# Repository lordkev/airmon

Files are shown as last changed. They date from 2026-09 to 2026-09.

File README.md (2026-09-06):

# AirMon

A USB-powered home air-quality monitor built around the **Keyestudio 2.8-inch ESP32-WROOM-32E touchscreen board**, with a small sensor carrier, printable enclosure, offline web dashboard, HTTP API, and optional Home Assistant integration.

**Prototype r0.1 — digital design, not yet physically validated.** The exact display-board mating connector and PMSA003I socket fit must be confirmed before ordering the PCB. Firmware compilation and CAD checks do not establish hardware operation. See the [validation ledger](docs/VALIDATION.md) for completed checks and remaining release gates.

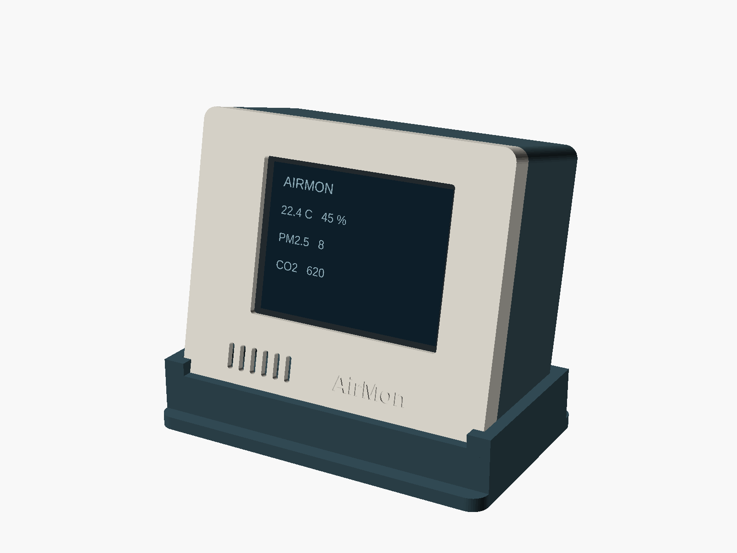
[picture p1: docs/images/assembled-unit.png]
Completed unit in its full enclosure and desktop stand


*CAD rendering of the full enclosure. LCD values are illustrative; this is not a photograph or firmware screenshot. Body: 100 × 82 × 44 mm, excluding the stand; shallow body: 100 × 82 × 30 mm.*

| Measurement | Sensor | Configuration |
|---|---|---|
| Temperature / relative humidity | SHT40 | Included on the carrier |
| PM1 / PM2.5 / PM10 | PMSA003I, Adafruit 4505 | Optional removable module |
| Actual CO₂ | SCD40, Adafruit 5187 | Optional STEMMA QT module |
| VOC / NOx indices | SGP41, Adafruit 6455 | Optional STEMMA QT module |

All sensors costing more than about $10 are optional. Add the PM module to meet the original temperature/humidity/PM2.5 minimum; the lowest-cost build measures temperature and humidity only. Gas indices do not identify individual chemicals, and AirMon does not replace a smoke or carbon-monoxide alarm.

## The circuit board

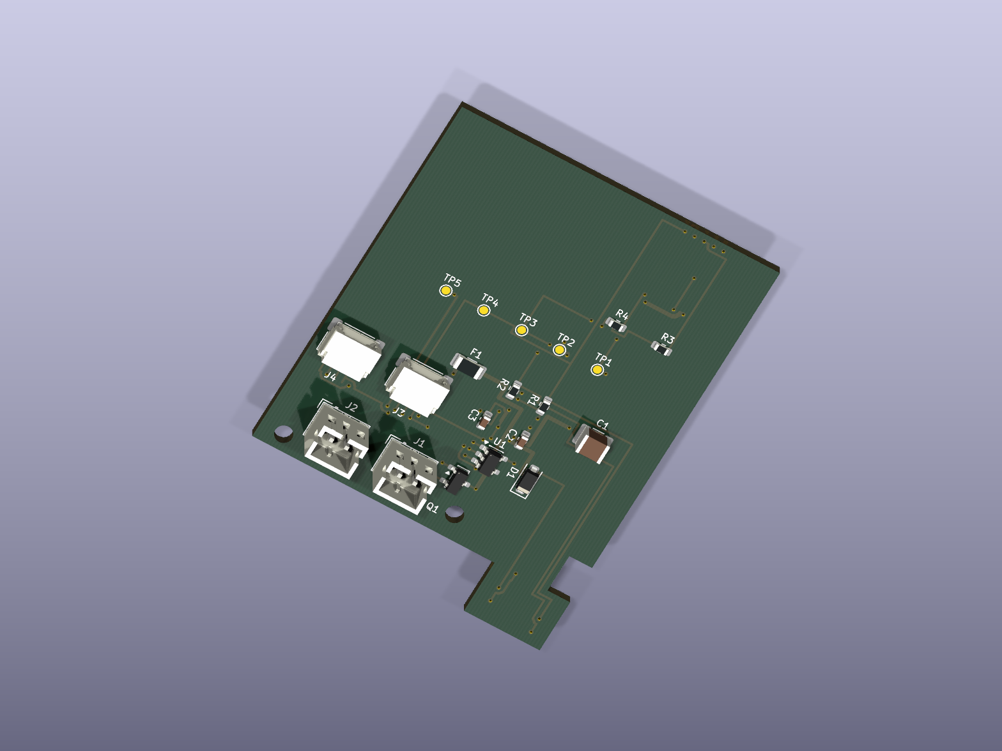
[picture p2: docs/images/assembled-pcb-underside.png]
Assembled sensor PCB, underside


*Native KiCad rendering of the routed 42 × 55 mm carrier, showing the regulator, protection, connectors, and test points. The SHT40 is on the opposite face of the extended tongue.*

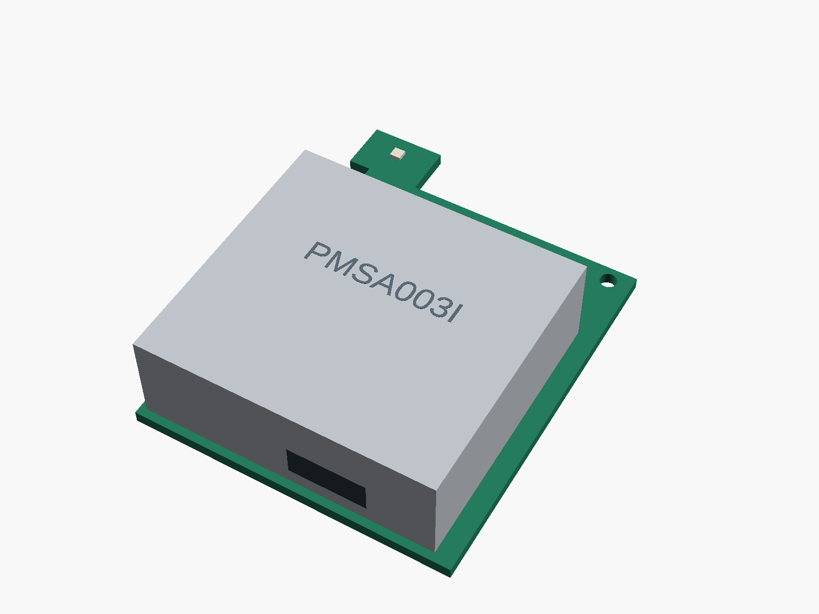
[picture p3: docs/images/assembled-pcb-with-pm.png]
Sensor carrier with optional PM module installed


*Mechanical rendering with the optional PMSA003I installed. Vendor modules and this view's carrier use simplified clearance envelopes; use the KiCad source and STEP for component-level details.*

## Build and use

1. Read [hardware and ordering](docs/HARDWARE.md), including the two connector checks.
2. Use the [BOM workbook](hardware/BOM.xlsx), [assembly CSV](hardware/assembly-bom.csv), and [purchasing CSV](hardware/purchasing-bom.csv).
3. Follow [printing and assembly](docs/ASSEMBLY.md), with the exploded CAD view.
4. [Build or flash the firmware](docs/FIRMWARE.md), then [configure and use AirMon](docs/USE.md).
5. Integrate through the [HTTP API](docs/API.md) or [MQTT/Home Assistant](docs/HOME_ASSISTANT.md).

## Deliverables

| Deliverable | Files |
|---|---|
| Editable electronics | [KiCad PCB](hardware/airmon.kicad_pcb), [schematic](hardware/airmon.kicad_sch), local libraries in `hardware/` |
| Manufacturing | [Gerber/drill ZIP](hardware/exports/airmon-gerbers.zip), [schematic PDF](hardware/exports/schematic.pdf), [assembly drawings and placement](hardware/exports/) |
| Mechanical | [PCB STEP](hardware/exports/airmon.step), [OpenSCAD source](enclosure/airmon.scad), [seven STL exports](enclosure/stl/) |
| Firmware | [ESP-IDF source](firmware/), [prototype binaries](release/firmware/) |
| Checks | [Validation ledger](docs/VALIDATION.md), [ERC](hardware/exports/erc.txt), [DRC](hardware/exports/drc.txt), [mesh checks](enclosure/mesh-validation.json), [CAD clearances](enclosure/clearance-validation.json) |
| Reproduction | [Development guide](docs/DEVELOPMENT.md), [requirements](PROMPT.md), [third-party notices](THIRD_PARTY.md) |

The project uses local Wi-Fi and HTTP. No cloud account or internet connection is required for normal readings; internet access is only used for optional clock synchronization and configured external services. History consists of 24 hours of one-minute means in RAM and resets at reboot.

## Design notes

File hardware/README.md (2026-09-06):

# AirMon carrier — prototype r0.1

Open `airmon.kicad_sch` and `airmon.kicad_pcb` in KiCad 10. Local symbols, footprints, and STEP models are included. The carrier is 42 × 55 mm overall, with a ventilated SHT40 tongue and optional PMSA003I mating socket.

Read [hardware and ordering](../docs/HARDWARE.md) before sending files to a manufacturer. **Exact display-board connector identification and the supplied PM socket fit remain unresolved physical checks.** ERC/DRC results apply to the digital design and do not remove these release gates.

- `exports/airmon-gerbers.zip`: copper, mask, silk, paste, outline, PTH and NPTH drill files.
- `exports/schematic.pdf`, `assembly-top.pdf`, `assembly-bottom.pdf`: electrical and assembly drawings.
- `exports/footprint-fit-1to1.pdf`: print at actual size to compare the supplied PM socket.
- `exports/placement-smt.csv`: SMT placement; J1/J2 require through-hole assembly separately.
- `BOM.xlsx`, `assembly-bom.csv`, `purchasing-bom.csv`: components and full purchasing data.
- `exports/airmon.step`: assembled carrier geometry.

J5 pad numbering follows Plantower, not the generic numbering in the Adafruit reference design. It must be checked against the supplied mating socket. Physical module models in enclosure illustrations are simplified envelopes.

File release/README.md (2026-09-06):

# AirMon prototype r0.1 deliverables

`firmware/` contains the four USB flash images, application-only OTA image, manifest, checksums, flash argument file, and dependency licenses. Flash instructions are in [docs/FIRMWARE.md](../docs/FIRMWARE.md).

Manufacturing files remain in [hardware/exports](../hardware/exports/), BOMs in [hardware](../hardware/), and print files in [enclosure/stl](../enclosure/stl/). This avoids maintaining duplicate copies with different revisions. The repository archive includes all of them.

**Prototype hold:** board-side connector identification, supplied PM socket fit, and physical electrical/mechanical/firmware tests are still pending. See [VALIDATION.md](../docs/VALIDATION.md). The renders illustrate the CAD design; they are not photographs of a tested product.

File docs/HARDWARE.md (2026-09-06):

# Hardware and ordering

## Release status

The PCB passes ERC/DRC. This is a **prototype engineering package**. Two purchased-part checks remain before fabrication: the display's exact 1.25 mm connector series and the PMSA003I supplied socket land pattern/mating height. Neither can safely be inferred from pitch alone. The BOM explicitly marks the unresolved board housing.

Match the delivered [Keyestudio board](https://www.keyestudio.com/products/28-inch-esp32-32e-display-screen-lcd-tft-module-with-touch-wroom-for-arduino) to [LCDWIKI E32R28T documentation](https://www.lcdwiki.com/2.8inch_ESP32-32E_Display). This project targets classic ESP32, 4 MB flash, ILI9341V LCD, and XPT2046 touch. Similarly sized boards may have different pinouts.

## Carrier and pins

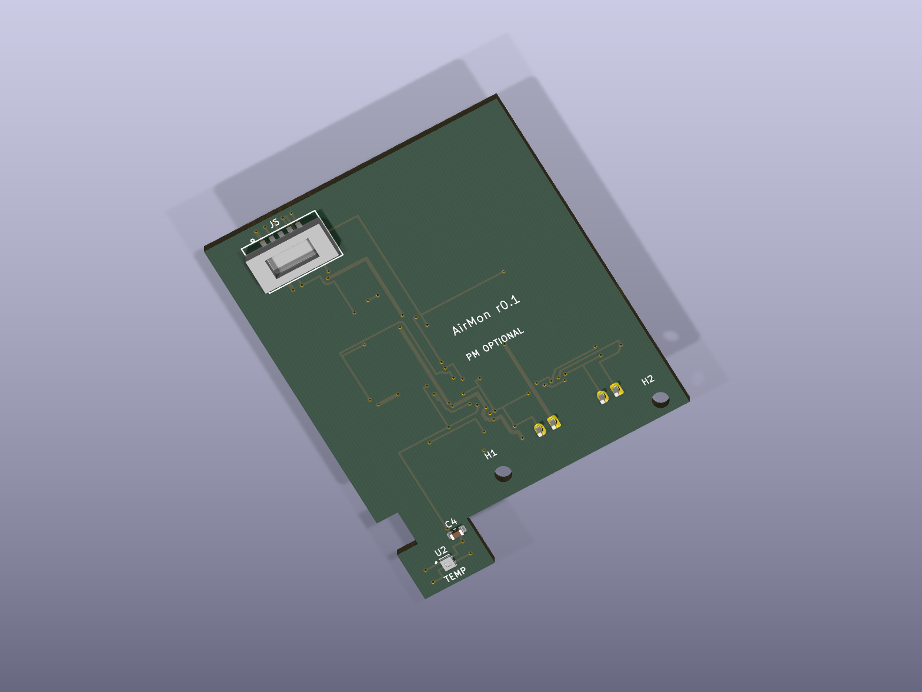
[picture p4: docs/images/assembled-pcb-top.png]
Native KiCad top view of the assembled carrier


*The optional PM socket is at the top of the board; SHT40 sits on the lower tongue. Simplified socket/sensor STEP envelopes still require a mating-height check.*

The carrier has a 42 × 48 mm main area plus a 10 × 7 mm SHT40 extension, 42 × 55 mm overall. It uses two copper layers and 1.6 mm FR-4. PMSA003I sits on top; power components and cable connectors sit underneath. Two M2 holes and printed edge guides support it.

| Function | ESP32 GPIO |
|---|---|
| LCD MOSI / MISO / SCLK | 13 / 12 / 14 |
| LCD CS / DC / backlight | 15 / 2 / 21 |
| Touch MOSI / MISO / SCLK | 32 / 39 / 25 |
| Touch CS / IRQ | 33 / 36 |
| Sensor SDA / SCL | 19 / 18 |
| Sensor 5 V enable | 22, LOW; shares red LED |
| Unused audio disable | 4, HIGH |
| SD deselect | 5, HIGH; card slot must stay empty |

LCD reset follows ESP32 EN. GPIO19/18 share the disabled microSD interface. The switched UART supply comes through the display-board Q5 circuit. GPIO22 HIGH does not guarantee full power disconnection because its gate drive is 3.3 V and its source is USB 5 V. Disconnect USB for service. Battery operation is unsupported. [Manufacturer schematic](https://www.lcdwiki.com/res/E32R28T/2.8inch_ESP32-32_Display_Schematic.pdf).

## Harnesses

These are schematic pin numbers, **not left-to-right visual instructions**. Identify pin 1 and verify continuity on the actual board. Do not rely on wire colors or assume the same view at opposite connector ends.

| Harness | Display end | Carrier end | Suggested color |
|---|---|---|---|
| POWER | UART P2 pin 1, switched USB 5 V | J1 pin 1 | Red |
| POWER | UART P2 pin 2, GND | J1 pin 2 | Black |
| I2C | SPI P3 pin 2, GPIO19 | J2 pin 1, SDA | Blue |
| I2C | SPI P3 pin 3, GPIO18 | J2 pin 2, SCL | Yellow |

Leave UART TXD/RXD pins 3/4, SPI GPIO23/GPIO27 pins 1/4, and connector shield/mounting positions out of the signal harness. Common ground comes through POWER. Target 100 mm wires, 26 AWG stranded. Carrier mating parts: JST **PHR-2** housings and **SPH-002T-P0.5S** contacts, mating to **B2B-PH-K-S(LF)(SN)**. Board ends must use confirmed matching pigtails or a positively identified housing/contact set; their exact MPN is still pending.

J1 and J2 are electrically different but mechanically interchangeable: label both harnesses and never swap them. J3/J4 use JST SH STEMMA QT pinout: 1 GND, 2 sensor 3.3 V, 3 SDA, 4 SCL. Do not apply 5 V to QT.

## Optional modules

| Module | Address | Procurement |
|---|---|---|
| SHT40 | `0x44` | Required SMT sensor on carrier |
| PMSA003I | `0x12` | [Adafruit 4505](https://www.adafruit.com/product/4505), bare I²C module with mating socket |
| SCD40 | `0x62` | [Adafruit 5187](https://www.adafruit.com/product/5187), plus QT cable |
| SGP41 | `0x59` | [Adafruit 6455](https://www.adafruit.com/product/6455), plus QT cable |

The PM part is not PMSA003 UART, PMS5003, or the larger Adafruit breakout. Socket numbering follows the [Plantower manual](https://cdn-shop.adafruit.com/product-files/4632/4505_PMSA003I_series_data_manual_English_V2.6.pdf): 1/2 VCC, 3/4 GND, 5 RESET, 6 NC, 7 SCL, 8 NC, 9 SDA, 10 SET. R3/R4 hold RESET/SET high at 3.3 V. Generic Eagle connector numbering in the Adafruit reference differs; check the mating view before translating numbers.

For later plug-in PM upgrades, have the supplied J5 socket consigned and fitted during PCBA assembly. If omitted, adding PM requires one-time socket soldering. No independently verified socket order code is claimed. Check it against the [1:1 footprint print](../hardware/exports/footprint-fit-1to1.pdf) and measure the assumed 2 mm mating height before fabrication.

## Power and I²C budget

Use a regulated 5 V, 2 A USB-A supply and short USB-A-to-C data cable. The following is a **design allowance, not a measurement**: display/ESP32 600 mA peak, PM 100 mA active plus 100 mA startup margin, and the 3.3 V sensor rail 250 mA including CO₂ pulses, gas heater, pull-ups, breakout LEDs, and margin. Total allowance: 1.05 A at 5 V. Validate the display-board USB connector/Q5 path and actual cable drop under load.

SCD40 specifies 205 mA peak and 15 mA average at 3.3 V. SGP41 specifies 3.0 mA typical measurement average and 4.6 mA maximum conditioning average at 3.3 V. Breakout overhead and pulse loads require bench testing. [SCD40 specifications](https://sensirion.com/products/catalog/SCD40), [SGP41 datasheet, table 2](https://sensirion.com/media/documents/5FE8673C/61E96F50/Sensirion_Gas_Sensors_Datasheet_SGP41.pdf).

AP2112K U1 is rated 600 mA and has ceramic input/output decoupling. At the 250 mA allowance, `(5 − 3.3) × 0.25 = 0.425 W` is an instantaneous dissipation estimate. The datasheet's 184 °C/W junction-to-ambient figure would imply a 78 °C rise if that load were continuous; that is not an acceptable assumed continuous operating point in warm ambient conditions. Expected average sensor current is much lower, but verify regulator temperature and rail droop fully populated. [AP2112 datasheet](https://www.diodes.com/assets/Datasheets/AP2112.pdf).

F1 is a 1 A hold resettable fuse in the carrier branch; Q1 protects against reverse input polarity. D1 is a transient suppressor, **not regulated overvoltage protection**: its clamp can exceed the LDO absolute input rating. Use regulated USB 5 V only. C1 provides local bulk capacitance; measure PM startup droop instead of assuming it is eliminated.

The carrier has 4.7 kΩ pull-ups per I²C line. Each referenced gas breakout has **two 10 kΩ branches per line**, on opposite sides of its MOSFET level shifter. When LOW, both branches contribute current; treating their supplies as 3.3 V gives a conservative 5 kΩ equivalent per installed breakout. Actual sensor-side voltage is affected by its onboard regulator. Check the delivered revisions and PM idle resistance.

| PM | CO₂ | VOC/NOx | Conservative LOW equivalent | LOW current, 3.3 V |
|---|---|---|---|---|
| Off | Off | Off | 4.70 kΩ | 0.70 mA |
| On | Off | Off | 4.70 kΩ | 0.70 mA |
| Off | On | Off | 2.42 kΩ | 1.36 mA |
| On | On | Off | 2.42 kΩ | 1.36 mA |
| Off | Off | On | 2.42 kΩ | 1.36 mA |
| On | Off | On | 2.42 kΩ | 1.36 mA |
| Off | On | On | 1.63 kΩ | 2.02 mA |
| On | On | On | 1.63 kΩ | 2.02 mA |

The table assumes PM adds no pull-ups; include any internal pull-up found by measurement. These LOW-current equivalents are not a complete level-shifter rise-time model. At 100 kHz, a 4.7 kΩ pull-up and assumed 200 pF bus give `tr ≈ 0.8473 × R × C = 0.80 µs`. Measure rise time and LOW voltage at the farthest module for all eight configurations. Capacitance and actual module pull-up currents have not been measured. All four sensor addresses are distinct.

## PCBway order package

After resolving the connector checks, upload [airmon-gerbers.zip](../hardware/exports/airmon-gerbers.zip) for two-layer, 1.6 mm FR-4, 1 oz copper. Specify solder mask both sides and a lead-free finish; no controlled impedance is required. Use the manufacturer's standard finish or ENIG for fine-pitch assembly. This layout uses approximately 0.25 mm minimum tracks and 0.20 mm clearance, with 0.30 mm via drills and 0.60 mm pads. Preserve the outline and SHT40 tongue exactly.

For assembly, supply [assembly-bom.csv](../hardware/assembly-bom.csv), [placement-smt.csv](../hardware/exports/placement-smt.csv), [fabrication drawing](../hardware/exports/fabrication-drawing.pdf), [top](../hardware/exports/assembly-top.pdf) and [bottom](../hardware/exports/assembly-bottom.pdf) drawings, and [schematic](../hardware/exports/schematic.pdf). Placement uses KiCad drill origin and millimetres; bottom coordinates are not X-negated. Confirm bottom orientation and polarized pin 1 in the assembler's preview. J1/J2 need a separate through-hole step; J5 is optional and may need consignment. Test points and holes are not purchased parts.

Do not wash or conformally coat over SHT40. Agree on a sensor-compatible assembly process. [BOM.xlsx](../hardware/BOM.xlsx) distinguishes listed prices, estimates, and unknown quotes, dated 2026-09-06. PCBA setup, stencil, shipping, taxes, and uncertain harness pricing are not included in a purported total.

## First power checks

With USB disconnected, verify no 5 V-to-GND short and check each harness conductor against the table. Flash the display with the carrier disconnected so GPIO22 is configured. Confirm UART P2 pin 1 is near 5 V relative to pin 2. Remove USB, connect the carrier without optional modules, then power while monitoring current.

Measure TP1 GND, TP2 SENSOR5V, TP3 SENSOR3V3, TP4 SDA, and TP5 SCL. Target TP3 at 3.3 V ±5%. PM needs 4.5–5.5 V at its input, including startup dips; use an oscilloscope. Unplug before adding each module. Record total current, rail minima, regulator temperature, I²C rise time, and behavior at minimum/maximum brightness for all eight module combinations. Finish with the [fully populated 24-hour run](VALIDATION.md#physical-acceptance-procedure).

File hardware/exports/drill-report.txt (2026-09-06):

Drill report for airmon.kicad_pcb
Created on 2026-09-06T13:42:37

Copper Layer Stackup:
    =============================================================
    L1 :  F.Cu                      front
    L2 :  B.Cu                      back

Drill file 'airmon-PTH.drl' contains
    plated through holes:
    =============================================================
    T1  0.300mm  0.0118"  (60 holes))
    T2  0.750mm  0.0295"  (4 holes))

    Total plated holes count 64

Drill file 'airmon-NPTH.drl' contains
    unplated through holes:
    =============================================================
    T1  2.200mm  0.0866"  (2 holes))

    Total unplated holes count 2

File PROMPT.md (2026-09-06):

# Keyestudio touchscreen air-quality monitor

## Summary

Build a USB-powered desktop monitor around the [Keyestudio 2.8-inch ESP32-32E touchscreen board](https://www.keyestudio.com/products/28-inch-esp32-32e-display-screen-lcd-tft-module-with-touch-wroom-for-arduino), with a compact custom sensor PCB, printable PLA enclosure, local web dashboard, HTTP API, and Home Assistant integration.

Use a landscape touchscreen layout. Temperature and humidity are included; PM, CO₂, and VOC/NOx modules can be purchased and plugged in independently. All configurations use the same firmware.

## Hardware and manufacturing

### Sensor configuration

| Measurement | Hardware | Installation |
|---|---|---|
| Temperature/humidity | Sensirion SHT40 | Assembled on sensor PCB |
| PM1, PM2.5, PM10 | Plantower PMSA003I bare module | Removable matching socket |
| Actual CO₂ | Adafruit SCD40 breakout, product 5187 | Internal STEMMA QT cable |
| VOC/NOx indices | Adafruit SGP41 breakout, product 6455 | Internal STEMMA QT cable |

Every sensor costing more than approximately $10 remains optional and independently installable after assembly.

### Sensor PCB and connections

- Design a two-layer KiCad PCB using standard 1.6 mm FR-4 and 1 oz copper. Minimize its outline around the PM socket, sensor placement, and connectors; it need not span the display board.
- Mount it behind the display using enclosure standoffs and short cable harnesses. Provide factory SMT assembly files; users install cables and optional modules.
- Connect I²C through the Keyestudio expansion connector: **GPIO19 SDA, GPIO18 SCL**, with 3.3 V logic. Keep microSD disabled and its slot empty because these pins share the SD interface. [Board pin allocation](https://www.lcdwiki.com/2.8inch_ESP32-32E_Display)
- Obtain USB-derived 5 V and ground from the UART connector using a power-only harness; leave UART signal pins disconnected. Reserve **GPIO22 low** to enable this supply, accounting for its shared red-LED function. Verify connector numbering and the delivered board revision against the [schematic](https://www.lcdwiki.com/res/E32R28T/2.8inch_ESP32-32_Display_Schematic.pdf).
- Feed the PM sensor from 5 V and provide a dedicated regulated 3.3 V sensor rail. Include decoupling, appropriate protection, test points, and a calculated startup/peak-current budget.
- Use keyed STEMMA QT connections for gas modules and expansion. Check combined I²C pull-ups and voltage levels with every supported module combination.
- Place the SHT40 at a ventilated lower edge on a thermally isolated PCB section, away from the display, processor, regulator, gas-sensor heaters, and PM exhaust.
- Keep the ESP32 antenna region clear of sensor modules, copper, and cables. Verify connector mating heights and cable bend space in assembled CAD.

### Manufacturing deliverables

Deliver editable KiCad sources and local libraries, schematic PDF, PCB STEP model, Gerber/drill ZIP, fabrication drawing, placement CSV, assembly drawings, and assembly BOM suitable for PCBway.

Provide a separate complete purchasing BOM covering the display board, components, optional modules, exact mating connectors and harnesses, fasteners, printed parts, and a 5 V USB supply. Include manufacturer part numbers, quantities, sourcing links, dated prices, and required/optional classifications.

## Enclosure

- Create a parametric OpenSCAD enclosure and export printable STLs alongside editable source.
- Use a landscape front bezel with a stable, slightly reclined desktop base, rear shell, and removable internal sensor mounts.
- Design around the display board’s approximately **86 × 50 mm** outline. Final enclosure depth follows the assembled sensor and cable clearances. [Mechanical documentation](https://www.lcdwiki.com/2.8inch_ESP32-32E_Display)
- Provide shallow and full-sensor rear-shell variants sharing the front bezel. The full version accommodates PM, CO₂, and VOC/NOx simultaneously.
- Target PLA, a 0.4 mm nozzle, 0.2 mm layers, support-free printing, and screws with captive nuts.
- Preserve touchscreen edge clearance so the bezel cannot press on the resistive panel. Include USB access, BOOT/RESET access, strain relief, and secure mounting through the board’s mounting holes.
- Separate PM intake and exhaust openings to limit recirculation. Give the temperature and gas sensors direct room-air exposure while limiting heat transfer from electronics.
- Supply print orientations, assembly illustrations, and a small fit-test print for fasteners and mating clearances.

## Firmware and interfaces

### Device firmware and touchscreen

- Use ESP-IDF targeting the classic **ESP32**, with pinned dependencies, ILI9341 display support, XPT2046 resistive-touch support, and LVGL using partial display buffers.
- Use separate SPI controllers for display and touch, following the board’s wiring. Reserve the repurposed expansion pins exclusively for sensor I²C.
- Show temperature, humidity, PM2.5, CO₂, and gas indices on the landscape overview. Tapping a metric opens its trend and sensor status; provide large touch targets and a settings page.
- Include first-use touch calibration, saved calibration, and a recalibration option. BOOT remains a fallback control: short press changes pages; a five-second press during normal operation opens Wi-Fi setup.
- Default backlight brightness to 30%, with adjustable brightness and a configurable dimming timer.
- Implement independent sensor drivers with CRC/checksum validation, startup timing, retries, and explicit absent, warming-up, valid, stale, and failed states.
- Use SHT40 readings for ambient measurements and SGP41 compensation. Apply Sensirion’s Gas Index Algorithm; expose VOC/NOx as indices, never estimated CO₂ or identified chemical concentrations.
- Provide documented CO₂ calibration controls and temperature correction. Disable automatic CO₂ baseline calibration by default until the user enables it under suitable placement conditions.

### Networking, web dashboard, and API

- On first boot, create a password-protected setup AP with credentials displayed onscreen, captive-portal support, and a direct setup address. Keep phone/browser provisioning as the primary Wi-Fi setup flow.
- Commit new Wi-Fi credentials after a successful connection. Preserve existing credentials through failed changes and network outages; allow physical re-entry to setup.
- Serve a responsive local dashboard with live measurements, sensor health, settings, and 24-hour charts. Store one-minute aggregates in RAM and indicate that history resets on reboot.
- Embed all web assets in firmware; require no cloud account, CDN, or internet connection for normal operation.
- Expose `GET /api/v1/readings`, `/status`, `/history`, and `/config`; `PUT /api/v1/config`; and `POST /api/v1/firmware`.
- Include measurement units, timestamps or uptime, reading age, and validity. Represent unavailable values as `null`.
- Protect configuration changes and firmware uploads with a per-device administrator credential. Keep measurement reads available on the local network and document HTTP’s security assumptions.
- Add optional MQTT configuration, Home Assistant discovery, stable device/entity identifiers, availability reporting, and automatic reconnection.
- Support browser firmware uploads with two OTA application slots and rollback. Keep compressed assets inside each application image and enforce flash/RAM budgets for the 4 MB board. Retain USB flashing and recovery.

## Validation and delivery

- **Electrical:** Pass ERC/DRC; review footprints, harness pinouts, shared GPIO functions, power startup, rail voltage under load, and every optional-sensor combination.
- **Mechanical:** Check assembled-model collisions, antenna clearance, airflow, touchscreen clearance, fasteners, printable meshes, and sliced orientations.
- **Software:** Test sensor parsing, corrupted data, missing sensors, history rollover, touch calibration, provisioning, configuration persistence, Wi-Fi/MQTT recovery, Home Assistant discovery, and interrupted OTA.
- **Physical prototype:** Verify enclosure fit, touch operation while assembled, viewing angle, fully populated power consumption, a 24-hour operating run, and temperature bias against a separate reference.
- **Documentation:** Include ordering, printing, assembly, tool installation, compilation, prebuilt firmware flashing, USB recovery, configuration, calibration, API examples, dashboard use, Home Assistant setup, and troubleshooting.
- **Release package:** Deliver editable sources, manufacturing files, complete BOMs, STLs, firmware binaries, documentation, and validation results. Clearly distinguish completed checks from physical tests still pending.

Defaults remain indoor desktop use, USB power, PLA, plug-in upgrades, and no firm overall budget cap. Battery operation, audio, persistent microSD logging, and additional gas species are outside the first version. Confirm the purchased Keyestudio revision matches the documented E32R28T hardware before fabrication; label the initial release as a prototype until physical validation is complete.

## Additional documentation requirement

Include renders of the assembled circuit board and the completed unit in its 3D-printed enclosure. Also provide an exploded assembly view showing the display board, sensor carrier, optional sensor modules, and enclosure parts.

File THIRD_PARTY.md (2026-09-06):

# Third-party materials

This private project's original source has not been assigned a public redistribution license. Third-party components retain their own licenses and notices.

- **KiCad community libraries:** selected standard footprints and STEP models are copied into `hardware/AirMon.pretty` and `hardware/models`. Local model paths were changed; the custom PMSA003I supplied-socket footprint/model and simple SHT40 envelope are project-generated. KiCad libraries use CC BY-SA 4.0 with the electronic-design exception. The upstream [license document](hardware/licenses/KiCad-LICENSE.md) and [KiCad policy](https://www.kicad.org/libraries/license/) explain the distinction between design use and library redistribution. Original STEP headers/footprint descriptions are retained.
- **Adafruit Industries:** PMSA003I, SCD4x, and SGP41 public reference PCB designs were consulted for mechanical and connector dimensions. Upstream URLs and exact commits appear in [the manifest](hardware/references/manifest.json). Those reference repositories use [CC BY-SA 3.0](hardware/licenses/Adafruit-CC-BY-SA-3.0.txt). The AirMon schematic/layout is newly generated; vendor display and gas-module illustrations are simplified envelopes, not redistributed vendor board CAD.
- **Sensirion:** the unmodified floating-point Gas Index Algorithm is vendored in `firmware/components/gas_index`, with [BSD-3-Clause license](firmware/components/gas_index/LICENSE) and [upstream commit](firmware/components/gas_index/UPSTREAM.md).
- **Espressif ESP-IDF v5.5.1:** Apache-2.0 SDK plus third-party components, including Wi-Fi/PHY libraries, mbedTLS, and cJSON. SDK and managed-component sources are fetched by the documented build workflow rather than committed here.
- **LVGL 9.2.2:** MIT. **ILI9341 2.0.1** and **mDNS 1.8.2:** see their bundled upstream license files. Dependency versions and hashes are pinned in `firmware/dependencies.lock`.

Copies of the relevant binary dependency licenses are included in [release/firmware/licenses](release/firmware/licenses/). Refer to the pinned SDK source for its complete component notices. Manufacturer datasheets are linked and hashed where downloaded; the original documents are not redistributed in the release package.

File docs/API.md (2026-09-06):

# HTTP API v1

Base URL: `http://DEVICE_IP/api/v1`. The same API is available at `http://192.168.4.1/api/v1` while connected to the setup AP. Requests and responses use UTF-8 JSON except the firmware binary upload and the noted text responses. The device does not grant cross-origin browser access.

## Authentication and errors

GET endpoints are readable without authentication. All mutations require `Authorization: Bearer TOKEN`, where TOKEN is the 32-character administrator credential displayed on the LCD. HTTP is not encrypted; use a trusted LAN. Missing/incorrect tokens return `401` and `{"error":"Administrator token required"}`.

Other error statuses include `400` invalid input/upload, `409` busy or unavailable calibration, `413` JSON outside the 1–2,048 byte limit, and `503` insufficient history-response memory. Error bodies normally contain an `error` string. Unknown `/api/` GET routes return `404`.

## Endpoints

| Method | Path after `/api/v1` | Result |
|---|---|---|
| GET | `/readings` | Current measurements, units, validity and age |
| GET | `/status` | Firmware/network/heap/config/sensor status |
| GET | `/history?limit=180&before=...` | Paginated minute aggregates |
| GET | `/config` | Redacted configuration |
| PUT | `/config` | Partial settings update; `202` means pending |
| POST | `/calibration/co2` | Forced CO₂ calibration request; `202` |
| POST | `/calibration/touch` | Begin LCD touch calibration; `200` text |
| POST | `/firmware` | Raw application binary; `200` text then reboot |

## Readings

```sh
curl http://DEVICE_IP/api/v1/readings
```

The response contains `uptime_ms`, `timestamp` (Unix seconds or `null`), and `metrics`. Each metric is an object with `value`, `unit`, `status`, and `age_ms`. Illustrative metric entry:

```json
{"value":22.4,"unit":"°C","status":"valid","age_ms":540}
```

| Key | Unit | Source |
|---|---|---|
| `temperature` | `°C` | SHT40 plus configured correction |
| `humidity` | `%` | SHT40 |
| `pm1`, `pm2_5`, `pm10` | `µg/m³` | PMSA003I atmospheric/environmental fields |
| `co2` | `ppm` | SCD40 actual CO₂ |
| `voc_index`, `nox_index` | `index` | Sensirion Gas Index Algorithm |

All eight keys are present. Unavailable values are `null`, never zero as a missing-data sentinel. Status is `absent`, `warming_up`, `valid`, `stale`, or `failed`. A reading expires after 5 seconds, or 15 seconds for CO₂. `age_ms` is elapsed time since the last received sample; it is `null` if no sample exists. A warming sample may have an age but still has a null value. These gas indices are not estimated CO₂, ppm of a particular VOC, or an AQI.

## Status

`GET /status` returns `version`, `device_id` (12 hexadecimal MAC-derived characters), `board`, `uptime_ms`, `free_heap`, `minimum_free_heap`, `wifi_connected`, `ip`, `ap_active`, `mqtt_connected`, `config_pending`, `config_result`, `touch_calibrated`, `ota_busy`, `history_points`, and `sensor_errors`.

Heap values are bytes. `sensor_errors` is a four-element counter array in SHT40, PMSA003I, SCD40, SGP41 order. Counters and history reset on reboot. Poll `config_pending` and `config_result` after an asynchronous configuration or CO₂ calibration request. No passwords or administrator token are included.

## History

```sh
curl 'http://DEVICE_IP/api/v1/history?limit=180'
```

The response shape is:

```json
{
  "resolution_seconds":60,
  "persistent":false,
  "points":[
    {"uptime_s":120,"timestamp":null,"temperature":22.4,"humidity":45.1,"pm1":null,"pm2_5":null,"pm10":null,"co2":null,"voc_index":null,"nox_index":null}
  ],
  "next_before":120
}
```

`limit` is 1–180, default 180. Both numeric query fields accept decimal digits only; signs, suffixes, fractions, uint32 overflow, and oversized/truncated query strings return `400`. `before` is an exclusive unsigned uptime-second boundary, not an epoch time. The latest eligible points are selected and returned oldest-to-newest. To fetch older pages, pass `next_before` as `before` and prepend their points. Stop on an empty/short page or `next_before:null`. Eight full pages cover 1,440 points. A full final page can legitimately require one extra empty request to establish the end.

Values are minute means of fresh valid samples. The incomplete current minute is omitted. Missing minutes/metrics remain null. UTC may be absent until SNTP succeeds; use uptime for stable ordering. Discard prior pagination state after a device reboot.

## Configuration

`GET /config` returns the fields below except passwords, plus `wifi_password_set` and `mqtt_password_set`. The PUT operation is a partial update despite its method name: omitted fields retain their values. Unknown fields and incorrect types are rejected.

| Field | Type / limits | Default |
|---|---|---|
| `name` | Nonempty string, at most 32 UTF-8 bytes | `AirMon xxxxxx` |
| `ssid` | Nonempty string, at most 32 UTF-8 bytes | Empty until provisioned |
| `password` | Empty for open Wi-Fi, otherwise 8–63 bytes | Empty |
| `brightness` | Integer, 5–100 percent | 30 |
| `dim_seconds` | Integer, 0–3,600; zero disables dimming | 120 |
| `temperature_offset` | Number, −10 to +10 °C | 0 |
| `altitude_m` | Integer, 0–3,000 m | 0 |
| `co2_asc` | Boolean | false |
| `mqtt_enabled` | Boolean | false |
| `mqtt_uri` | String, at most 192 bytes; `mqtt://` or `mqtts://` when enabled | Empty |
| `mqtt_user` | String, at most 64 bytes | Empty |
| `mqtt_password` | String, at most 128 bytes | Empty |

Control characters are rejected in strings. Use the separate MQTT credential fields; credentials embedded in broker URIs are rejected because the URI is returned by GET config. Password omission preserves a stored password, while `"password":""` explicitly clears it. Do not PUT the GET response wholesale: the two read-only password-set flags are not accepted input fields. A Wi-Fi SSID is required in the resulting configuration, including for a first settings update.

```sh
curl -X PUT http://DEVICE_IP/api/v1/config \
  -H 'Authorization: Bearer TOKEN' -H 'Content-Type: application/json' \
  --data '{"ssid":"My Wi-Fi","password":"replace-this-password","name":"Living room"}'
```

`202 {"status":"pending"}` means the change was queued. New Wi-Fi credentials are tested for up to 40 seconds before persistence. Failed changes retain/restore the previous settings. A concurrent configuration or firmware update returns `409`. Poll `/status`; connection changes may require reconnecting to the new device IP. The setup AP closes 60 seconds after a successful connected save.

## Calibration

```sh
curl -X POST http://DEVICE_IP/api/v1/calibration/co2 \
  -H 'Authorization: Bearer TOKEN' -H 'Content-Type: application/json' \
  --data '{"reference_ppm":420}'
```

Use your actual known reference, not the example blindly. `reference_ppm` must be an integer from 400–2,000. CO₂ must be fresh/valid and periodic measurement must have run for at least three minutes. Success returns `202 {"status":"calibration_pending"}`; completion/failure appears in `config_result`. This is not a substitute for stable reference air.

```sh
curl -X POST http://DEVICE_IP/api/v1/calibration/touch \
  -H 'Authorization: Bearer TOKEN'
```

Touch calibration takes place on the LCD. The response is plain text, `Touch calibration started on the display`.

## Firmware upload

```sh
curl -X POST http://DEVICE_IP/api/v1/firmware \
  -H 'Authorization: Bearer TOKEN' -H 'Content-Type: application/octet-stream' \
  --data-binary @release/firmware/airmon.bin
```

Send a normal Content-Length upload of the application `.bin`, not multipart/form-data or a chunked request. The maximum image size is the inactive slot size, 1,966,080 bytes. Success returns plain text `Firmware validated. Rebooting.` The device reboots shortly afterwards. Invalid/incompatible/incomplete uploads return `400` and keep the current image selected. See [firmware and recovery](FIRMWARE.md) for rollback behavior and pending hardware tests.

## Live acceptance checks

Once a prototype is flashed and reachable, run the read-only checker from the repository root:

```sh
python3 scripts/test_device_api.py http://DEVICE_IP
```

It checks real HTTP responses, metric/null/freshness semantics, history pagination, malformed query rejection, redacted configuration, dashboard delivery, and three concurrent readers. The JSON report defaults to `tmp/device-api-validation.json`. It sends no configuration, calibration, or firmware updates. An empty history can pass structural checks; it is not evidence of a 24-hour run. Hardware-dependent tests in the validation ledger remain separate.

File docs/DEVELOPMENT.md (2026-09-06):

# Reproducing the design

The checked-in native files are editable without regeneration. Scripts that generate the board or schematic overwrite their output; preserve manual edits before running them. The repository does not include downloaded SDKs, native applications, virtual environments, or build caches.

## Tools

| Area | Version used |
|---|---|
| Electronics | KiCad 10.0.6, including its `pcbnew` Python module |
| Enclosure | OpenSCAD 2026.09.05, manifold backend |
| Mechanical checks | Python 3.12; CadQuery 2.8.0, trimesh 5.1.0, manifold3d 3.5.2 |
| Firmware | ESP-IDF v5.5.1, esptool 4.12.0, locked managed components |
| Slicing check | Bambu Studio 02.08.02.61; isolated A1 0.4 mm / Generic PLA reference profile |
| Host software tests | Clang with AddressSanitizer/UndefinedBehaviorSanitizer; Node 24 and Playwright/Chrome |
| BOM authoring | Node with `@oai/artifact-tool`; CSVs and XLSX are already delivered |

Install KiCad from [kicad.org](https://www.kicad.org/download/) and OpenSCAD from [openscad.org](https://openscad.org/downloads.html). Set `KICAD_CLI`, `KICAD_SHARE`, and `OPENSCAD` if executables/libraries are outside normal locations. `KICAD_CONFIG_HOME` can point to a private configuration directory. Run PCB Python scripts with KiCad's bundled Python, which has `pcbnew` available; other scripts use ordinary Python.

## Electronics

For export from the existing native files:

```sh
python3 scripts/export_hardware.py
KICAD_PYTHON scripts/check_netlist.py
python3 scripts/fabrication_drawing.py
```

Replace `KICAD_PYTHON` with the executable path for KiCad's Python. `fabrication_drawing.py` needs `reportlab`. The exporter requires successful ERC/DRC, produces PDFs/netlist/Gerbers/drills/placement/STEP, and verifies that the manufacturing ZIP contains the copper layers as well as drills. The independent connectivity check compares every connected schematic pin with PCB pad nets.

Full regeneration, only when you intend to replace the editable layout:

```sh
KICAD_PYTHON scripts/build_hardware.py
python3 scripts/prepare_models.py
KICAD_PYTHON scripts/build_hardware.py
KICAD_PYTHON scripts/route_hardware.py
python3 scripts/build_schematic.py
python3 scripts/export_hardware.py
KICAD_PYTHON scripts/check_netlist.py
```

The first board pass prepares footprint copies; model preparation attaches local STEP paths; the second pass loads those models. Routing uses a two-layer grid search and explicit fine-pitch escape rules. Inspect regenerated geometry and drawings even after a clean DRC. `components.json` records the net/pad specification. Vendor sources and commits are in [the reference manifest](../hardware/references/manifest.json).

To render the actual populated PCB:

```sh
kicad-cli pcb render --side bottom --rotate '25,0,30' --zoom 0.65 \
  --quality high --background opaque --floor --width 1600 --height 1200 \
  -o docs/images/assembled-pcb-underside.png hardware/airmon.kicad_pcb
```

Use `--side top` and a different output name for the top view. Documentation enclosure/module renders come directly from OpenSCAD; no generated product photography is used.

## Mechanical export and checks

```sh
python3 -m venv .venv-cad
. .venv-cad/bin/activate
python -m pip install cadquery==2.8.0 trimesh==5.1.0 manifold3d==3.5.2 networkx
python scripts/export_enclosure.py
python scripts/validate_meshes.py
python scripts/export_clearance_step.py
python scripts/check_clearances.py
python scripts/check_clearances.py --shallow
```

The exporter creates all seven STLs, full/shallow collision envelopes, and three enclosure documentation views. Mesh validation welds only export-roundoff vertices at 0.00001 mm precision and removes degenerate/duplicate faces; it does not fill holes. It checks watertightness, normals, body count, volume preservation, and placement above the print bed.

The clearance check intersects the actual KiCad STEP carrier with the printed parts and simplified vendor component envelopes. Full configuration has 28 pair checks; shallow has 10. A zero intersection is only a check of represented solids: screws, cables, connector mating tolerances, airflow, and thermal behavior still require a physical prototype.

`python scripts/check_slicing.py` runs Bambu Studio locally using an isolated data directory. Set `BAMBU_APP` to its app bundle if needed. It flattens bundled profile inheritance, applies the documented print settings, slices each STL, and records results. Files under `tmp/slicing/` are validation artifacts for a reference printer, not universal print-ready G-code. Re-slice STLs with your actual printer and filament profile.

## Firmware and tests

Follow [firmware installation](FIRMWARE.md) for the SDK. From the repository root:

```sh
scripts/test_core.sh
scripts/test_config.sh
scripts/build_firmware.sh size
python3 scripts/package_firmware.py
```

Core tests cover sensor CRC/checksum parsing, atmospheric PM field selection, invalid readings, history means/gaps/rollover, touch transforms, and token comparison. Configuration tests compile the production parser/persistence code with a transactional NVS fake. They exercise input limits, password redaction, persistence across simulated reboot, and failed-commit preservation. The fake does not establish real flash durability or FreeRTOS synchronization.

For browser testing, install the `playwright` npm package in an isolated development environment with Google Chrome available, then run:

```sh
node tests/test_web.mjs
```

It serves the actual embedded HTML against a simulated API, checks desktop/390 px mobile layouts, metric states, paginated history, authorization errors, password-preservation semantics, and loss of connection. It does not emulate the ESP32 HTTP server or Wi-Fi stack. No external server is contacted by the fixture.

The XLSX builder reads `hardware/bom-data.json` and requires `@oai/artifact-tool`:

```sh
node scripts/build_bom.mjs
```

The resulting workbook and CSVs are usable without that tool. Prices labeled as estimates remain estimates. Editing source JSON alone does not update the exported BOMs.

## Prototype package

`release/firmware/manifest.json` contains exact flash offsets, byte counts, hashes, and remaining OTA space. Run `python3 scripts/package_firmware.py` only after a successful build. `scripts/audit_release.py` checks required artifacts, local documentation links, ZIP layers, binary hashes, mesh reports, and reference to the renders.

Physical acceptance results belong in [VALIDATION.md](VALIDATION.md), with measured board revision, sensor serial/revision information, test date, and observations. Do not change the prototype designation merely because software/CAD checks pass.

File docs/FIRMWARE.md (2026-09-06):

# Firmware: flashing, building, and recovery

The firmware targets **classic ESP32 with 4 MB flash**, without PSRAM. It has been compiled successfully; LCD orientation, touch, Wi-Fi setup, sensors, and OTA still require testing on the exact board. Keep the microSD slot empty. Do not flash an ESP32-C6/S3 image onto this board.

## Flash the supplied prototype

Install Python 3.12 and create an isolated tooling environment. Commands below assume a terminal at the repository root; substitute your serial port for `PORT`.

```sh
python3 -m venv .venv
. .venv/bin/activate
python -m pip install esptool==4.12.0
cd release/firmware
shasum -a 256 -c SHA256SUMS
python -m esptool --chip esp32 --port PORT --baud 460800 write_flash @flash_args
```

On macOS, list ports with `ls /dev/cu.*`; the USB serial device should appear when the data cable is connected. Linux commonly uses `/dev/ttyUSB0`; Windows uses a COM port. Use a data-capable USB-A-to-C cable. If needed, install the USB-to-serial driver corresponding to the chip on the delivered display board; do not assume a chip based only on the product title.

Disconnect the sensor carrier for the first display-board flash. If automatic bootloader entry fails, hold BOOT, press/release RESET, then release BOOT when the upload begins. Try 115200 baud if uploads fail at 460800. Press RESET after flashing. Open a 115200-baud serial monitor for diagnostic logs; credentials are displayed on the LCD, not printed to the log.

`flash_args` writes these images without erasing the entire flash:

| Offset | Image | Purpose |
|---|---|---|
| `0x1000` | `bootloader.bin` | ESP-IDF bootloader with rollback |
| `0x8000` | `partition-table.bin` | 4 MB partition map |
| `0xf000` | `ota_data_initial.bin` | Initial OTA selection metadata |
| `0x20000` | `airmon.bin` | Application, including dashboard assets |

Check [manifest.json](../release/firmware/manifest.json) and hashes before flashing. The application alone is used for browser OTA; do not upload a bootloader, merged flash image, or partition table through the web interface.

## Build from source

Install Git, CMake, Ninja, and Python 3.12. The pinned SDK is **ESP-IDF v5.5.1**, with recursively checked-out submodules. Follow Espressif's [platform-specific prerequisites](https://docs.espressif.com/projects/esp-idf/en/v5.5.1/esp32/get-started/index.html) if your host lacks build tools.

```sh
mkdir -p .tools
git clone --recursive --branch v5.5.1 --depth 1 https://github.com/espressif/esp-idf.git .tools/esp-idf
export IDF_TOOLS_PATH="$PWD/.tools/idf"
.tools/esp-idf/install.sh esp32
. .tools/esp-idf/export.sh
scripts/build_firmware.sh
```

The script embeds the web page using deterministic gzip compression, then runs `idf.py build`. `firmware/dependencies.lock` pins managed components, including LVGL 9.2.2, ILI9341 2.0.1, and mDNS 1.8.2. Sensirion's Gas Index Algorithm source and license are vendored with an upstream commit reference.

For configuration and development flashing:

```sh
cd firmware
idf.py menuconfig
idf.py -p PORT flash monitor
```

Exit the IDF monitor with Ctrl+]. To regenerate the supplied binary bundle after a successful build, run `python3 scripts/package_firmware.py` from the repository root. `sdkconfig.defaults` is authoritative for a fresh build. Existing `sdkconfig` values override defaults; review changes with `idf.py menuconfig` when updating an existing checkout.

## Flash and RAM limits

Two OTA slots each contain `0x1e0000` bytes (1,966,080 bytes). The prototype image uses about 1.33 MB, leaving about 33% in each slot; exact values are in the manifest. NVS occupies `0x9000–0xefff`. History is a 1,440-point RAM ring, not a filesystem or SD log.

The measured build uses 146,036 bytes of static DRAM and 99,391 bytes of IRAM. Static DRAM headroom is 34,700 bytes; additional runtime heap regions are separate from that linker figure. LVGL's pool is limited to 48 KiB, its two partial DMA buffers total 25,600 bytes, Wi-Fi dynamic RX/TX buffers are capped at eight each, and the MQTT outbox is bounded at 8 KiB. This is a build budget, not proof of runtime headroom. Track `free_heap` and `minimum_free_heap` from the status endpoint through TLS connection, chart loading, OTA, and the 24-hour test.

## Browser updates and rollback

Open Settings, enter the administrator token, choose **application `airmon.bin`**, and select Upload firmware. The device checks image size, classic ESP32 chip ID, project name, and ESP-IDF image validity before selecting the inactive slot. Do not disconnect power while updating. A failed transfer leaves the current image selected. A new image that resets before startup validation can roll back to the previous image. Startup is marked valid after its services initialize and a ten-second interval; it does not wait for optional sensors or a reachable router.

This is not signed-firmware verification: anyone with the administrator token can upload a compatible image. Actual interrupted-transfer, interrupted-flash, and rollback tests remain pending on hardware.

## Recovery and factory reset

If the application fails to start, enter the ROM bootloader with BOOT/RESET and reflash the complete supplied bundle over USB. NVS is preserved by normal flashing. Firmware deliberately does not silently erase NVS when initialization fails.

A factory reset is a separate destructive action: it deletes Wi-Fi/MQTT settings, administrator/AP credentials, touch calibration, and installed firmware. Only when you intend that reset, run:

```sh
python -m esptool --chip esp32 --port PORT erase_flash
python -m esptool --chip esp32 --port PORT --baud 460800 write_flash @flash_args
```

New credentials are generated after the reset. Ordinary network recovery needs only a five-second BOOT press during normal operation to reopen setup; it does not require a factory reset.

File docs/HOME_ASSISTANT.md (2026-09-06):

# MQTT and Home Assistant

MQTT is optional and disabled by default. AirMon's LCD, web page, and HTTP API work without a broker.

1. Configure a broker and add Home Assistant's [MQTT integration](https://www.home-assistant.io/integrations/mqtt/).
2. In AirMon web Settings, enter the administrator token, enable MQTT, and enter the broker URI, username, and password. Use `mqtt://192.168.1.10:1883` for a trusted LAN or `mqtts://broker.example.com:8883` for TLS with a publicly trusted certificate. Use the separate credential fields; URI-embedded credentials are rejected.
3. Save, wait for “Settings saved,” and check `mqtt_connected:true` through the status endpoint. Self-signed/custom CA certificates and mutual TLS are not supported by this prototype's configuration UI.
4. Look for the AirMon device in Home Assistant's MQTT devices. Discovery creates eight entities; uninstalled or warming sensors remain unavailable.

## Topic contract

`DEVICE_ID` is the 12-character identifier returned by `/api/v1/status`.

| Topic | Payload / retention |
|---|---|
| `airmon/DEVICE_ID/state` | Flat JSON with all eight metric keys; values or null; not retained; about every 10 seconds |
| `airmon/DEVICE_ID/availability` | `online` / `offline`; retained; last will is `offline` |
| `airmon/DEVICE_ID/availability/METRIC` | `online` only for a fresh valid metric; retained |
| `homeassistant/sensor/airmon_DEVICE_ID/METRIC/config` | Retained discovery JSON |

Each entity requires both device and metric availability to be online. Discovery uses stable unique IDs `airmon_DEVICE_ID_METRIC`, measurement state class, and an expiry of 35 seconds. CO₂ uses the carbon-dioxide device class; PM uses PM1/PM2.5/PM10 classes; VOC/NOx are generic index sensors, not AQI or gas concentration classes.

AirMon subscribes to `homeassistant/status` and republishes discovery/state when it receives `online`. It reconnects after broker outages and republishes on connection. The broker keepalive is 30 seconds and the reconnect delay is 5 seconds. When disabling MQTT, existing retained discovery records remain in the broker; delete those specific topics if you want to remove the old entities permanently.

If discovery does not appear, verify the broker address, credentials, ACL permission for the topic prefixes, and Home Assistant's discovery setting. A broker ACL should permit AirMon to publish its own `airmon/DEVICE_ID/#` and discovery prefix and subscribe to `homeassistant/status`. TLS certificate validation also requires a correct clock; the prototype obtains time from `pool.ntp.org` using SNTP. Actual broker restart, discovery, and last-will timing tests are listed as pending in the validation ledger.

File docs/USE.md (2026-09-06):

# Setup and daily use

## First boot

1. Connect USB power and complete the four-point touch calibration, tapping and releasing each cross. If calibration is inaccurate, repeat it from Settings.
2. Open **Settings → Wi-Fi setup / credentials**. BOOT held for five seconds during normal operation opens this page even if touch is unusable.
3. Join the displayed `AirMon-xxxxxx` Wi-Fi network using its unique 16-character password. If the captive page does not open, browse to **http://192.168.4.1**. Stay connected if your phone reports that this network has no internet.
4. In web Settings, enter the displayed 32-character administrator token. The LCD splits it across two lines: concatenate them without a space or newline. Enter your 2.4 GHz home Wi-Fi SSID and password, then Save settings.
5. Allow up to 40 seconds for the connection test. Settings are saved only after connection succeeds. A failed change restores the previous configuration. On success, the setup AP closes after 60 seconds; reconnect your phone to the home network.
6. Open the IP address displayed by AirMon, or `http://airmon-xxxxxx.local` using the same suffix. If multicast DNS is unavailable, use the router's DHCP lease list or reserve an IP address.

The setup AP is WPA2 protected. Its password and administrator token persist across reboots. The web token is held in the page's memory and disappears on reload/close; it is not stored in browser local storage. The credentials page can be reopened physically at any time.

## LCD and dashboard

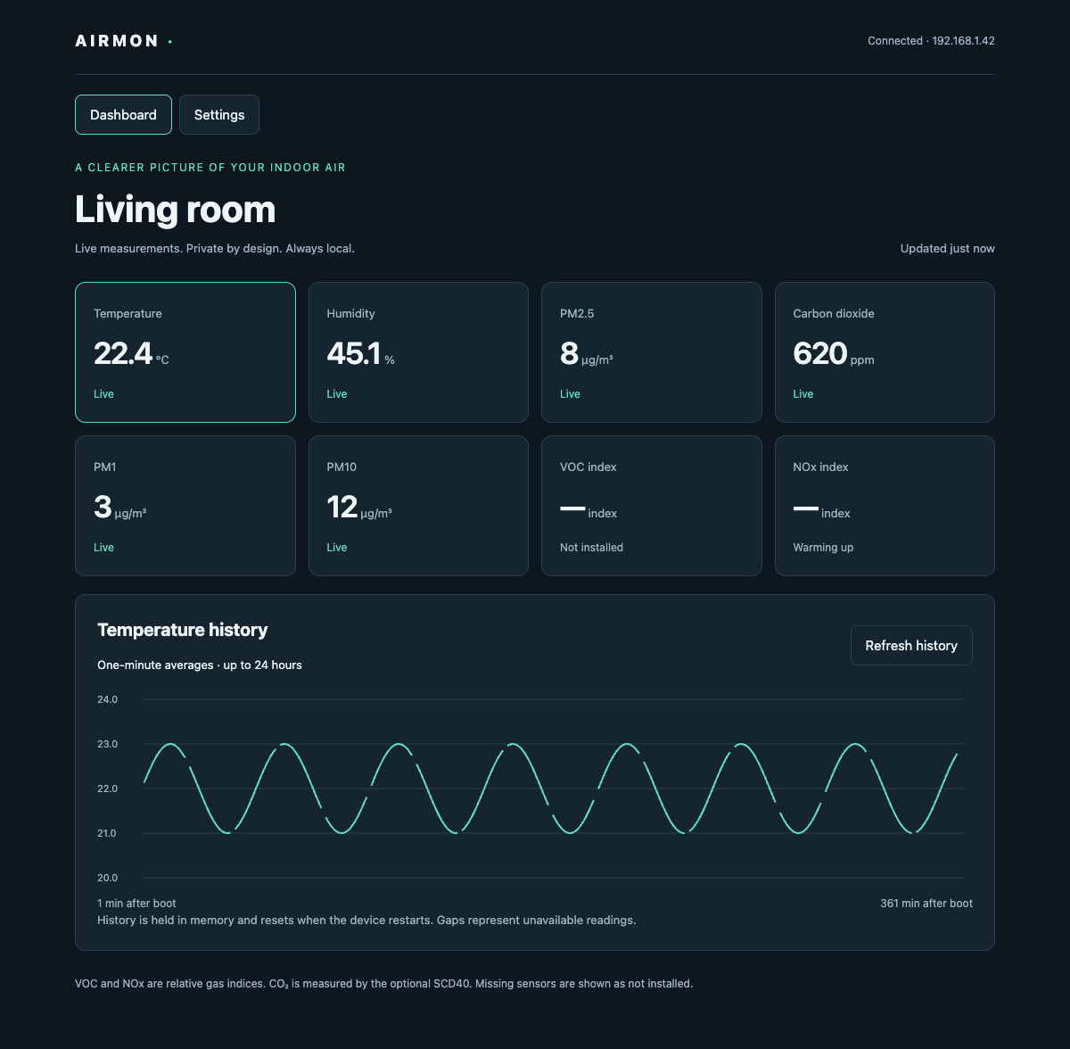
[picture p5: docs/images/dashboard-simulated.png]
Embedded web dashboard with simulated readings


*Actual dashboard rendered in Chrome against a simulated API. These are test values, not measurements from a physical prototype.*

The landscape overview shows eight metrics. Tap a tile for its trend and sensor state. Settings controls brightness and touch calibration; network and sensor settings are primarily configured in the web page. A short BOOT press cycles overview, trend, and settings pages. The default backlight is 30%; it dims after 120 seconds without input. Brightness is adjustable from 5–100%, and setting the dim timer to zero disables dimming.

The dashboard refreshes readings every three seconds. Select a metric for its chart. Charts hold up to 24 hours of one-minute means, with gaps for missing or invalid data. No history is written to flash; rebooting starts a new history. SNTP provides UTC when reachable. Without internet, the monitor uses uptime and continues measuring normally.

| Display/API state | Meaning |
|---|---|
| `absent` | Sensor address not detected; optional module may be uninstalled |
| `warming_up` | Detected but initial settling is incomplete |
| `valid` | Fresh validated reading |
| `stale` | Recent measurement failed or is too old; value is unavailable |
| `failed` | Repeated errors or initialization/self-test failed |

PMSA003I has a 30-second firmware warmup. CO₂ updates about every five seconds. Gas indices are held in warmup for **90 minutes for VOC and six hours for NOx** after sensor initialization, reflecting the datasheet's index settling guidance. They relearn after reboot. SHT40 temperature and humidity are required for real-time gas compensation; if those readings are unavailable, gas indices become stale. Gas indices represent relative changes, not identified chemical concentrations. [SGP41 startup specification](https://sensirion.com/media/documents/5FE8673C/61E96F50/Sensirion_Gas_Sensors_Datasheet_SGP41.pdf).

## Calibration and placement

Place the monitor on an indoor desk or shelf with clear air around the vents, away from direct sun, a heating outlet, and direct exhaled breath. Keep intake and exhaust uncovered. Its humidity/temperature tongue reduces heat coupling but does not prove ambient accuracy.

For temperature correction, place an independent reference nearby, allow both instruments to equilibrate, and set **Temperature correction** to `reference − AirMon`. Compare at multiple temperatures and brightness settings; a changing bias needs a mechanical or thermal correction rather than a single offset. Relative humidity is not recalibrated by the temperature offset.

SCD40 automatic self-calibration is **off by default**. Enable it only where the sensor regularly encounters fresh outdoor-equivalent air under the manufacturer's conditions. Set installation altitude in metres. For forced CO₂ recalibration, use a known reference between 400 and 2,000 ppm and leave the sensor operating in stable reference air for at least three minutes before requesting calibration. Do not assume arbitrary room air is 400 ppm. The result appears in device status. Consult [Sensirion's SCD40 documentation](https://sensirion.com/products/catalog/SCD40) for reference conditions and calibration limitations.

## Network and security assumptions

Normal reads need no authentication. Configuration, calibration, and firmware updates need the per-device bearer token. HTTP on the LAN is not encrypted; Wi-Fi/MQTT credentials are stored in device NVS without flash encryption. Use a trusted private network, and do not expose the HTTP port directly to the internet. MQTT is optional; `mqtts://` uses publicly trusted server certificates. Device and broker availability are separate.

Wi-Fi outages preserve settings and readings on the LCD while the device reconnects. BOOT can reopen setup. Leaving a Wi-Fi or MQTT password field blank preserves it; use the explicit clear-password checkbox to clear it. Configuration changes are asynchronous: wait for “Settings saved” or the failure result before making another change.

## Troubleshooting

| Symptom | Check |
|---|---|
| Blank LCD | Correct ESP32 image, USB supply/data cable, RESET, serial log; LCD pinout must match E32R28T |
| Touch misses targets | Recalibrate; check that bezel edges do not press on the panel |
| PM absent | Bare PMSA003I, correct socket/pins, GPIO22 LOW, 5 V under load; keep SD empty |
| Both gas modules absent | QT pinout and 3.3 V, correct Adafruit boards, carrier harness SDA19/SCL18 |
| Gas indices warming for hours | Expected settling; avoid repeated power cycling |
| All sensors fail together | Common ground, swapped POWER/I2C harness, bus held LOW, supply droop |
| Temperature too high | Vents, proximity to heat, brightness, PM exhaust and thermal-reference comparison |
| Setup page will not open | Join device AP, disable automatic network switching temporarily, use 192.168.4.1 |
| Settings show unauthorized | Re-enter full 32-character token from LCD; no spaces between its two lines |
| Wi-Fi change fails | 2.4 GHz network, SSID spelling, password; previous settings remain saved |
| Reboots during TLS/OTA | Supply dip and minimum-free-heap log; runtime stress validation is still pending |

See [USB recovery](FIRMWARE.md#recovery-and-factory-reset) if the application cannot boot.

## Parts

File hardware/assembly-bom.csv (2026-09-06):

References | Qty | Part | Manufacturer | MPN | Package | Unit USD | Line USD | Price basis | Installation | Assembly notes | Source URL | Date
U1 | 1 | 3.3 V 600 mA LDO | Diodes Incorporated | AP2112K-3.3TRG1 | SOT-23-5 | 0.45 | 0.45 | Estimate | Required | SMT bottom | https://www.diodes.com/assets/Datasheets/AP2112.pdf | 2026-09-06
U2 | 1 | Temperature and humidity | Sensirion | SHT40-AD1B-R2 | DFN-4 1.5 x 1.5 mm | 3.5 | 3.5 | Estimate | Required | SMT top; no wash or coating over sensor | https://sensirion.com/products/catalog/SHT40 | 2026-09-06
Q1 | 1 | Reverse input polarity MOSFET | Alpha & Omega | AO3401A | SOT-23 | 0.25 | 0.25 | Estimate | Required | SMT bottom; source faces protected rail | https://www.aosmd.com/products/mosfets/low-voltage-mosfets-12v-30v/ao3401a | 2026-09-06
F1 | 1 | 1 A resettable fuse | Littelfuse | 1206L100/16YR | 1206 | 0.8 | 0.8 | Estimate | Required | SMT bottom | https://www.littelfuse.com/products/polyswitch-resettable-pptcs/surface-mount/1206l.aspx | 2026-09-06
D1 | 1 | 5 V transient suppressor | Littelfuse | SMF5.0A | SOD-123F | 0.4 | 0.4 | Estimate | Required | SMT bottom; cathode to SENSOR5V | https://www.digikey.com/en/products/detail/littelfuse-inc/SMF5-0A/3429605 | 2026-09-06
C1 | 1 | 47 uF 10 V X5R bulk capacitor | Murata | GRM32ER61A476KE20L | 1210 | 0.85 | 0.85 | Estimate | Required | SMT bottom | https://www.murata.com/en-us/products/productdetail?partno=GRM32ER61A476KE20L | 2026-09-06
C2 | 1 | 4.7 uF 10 V X5R input capacitor | Murata | GRM188R61A475KE15D | 0603 | 0.15 | 0.15 | Estimate | Required | SMT bottom | https://www.murata.com/en-us/products/productdetail?partno=GRM188R61A475KE15D | 2026-09-06
C3 | 1 | 10 uF 10 V X5R output capacitor | Murata | GRM188R61A106KE69D | 0603 | 0.2 | 0.2 | Estimate | Required | SMT bottom | https://www.murata.com/en-us/products/productdetail?partno=GRM188R61A106KE69D | 2026-09-06
C4 | 1 | 100 nF 16 V X7R bypass capacitor | Murata | GRM188R71C104KA01D | 0603 | 0.05 | 0.05 | Estimate | Required | SMT top | https://www.murata.com/en-us/products/productdetail?partno=GRM188R71C104KA01D | 2026-09-06
R1 R2 | 2 | 4.7 kohm 1% I2C pull-up | Yageo | RC0603FR-074K7L | 0603 | 0.03 | 0.06 | Estimate | Required | SMT bottom | https://www.yageo.com/en/ProductSearch | 2026-09-06
R3 R4 | 2 | 10 kohm 1% PM control pull-up | Yageo | RC0603FR-0710KL | 0603 | 0.03 | 0.06 | Estimate | Required | SMT bottom | https://www.yageo.com/en/ProductSearch | 2026-09-06
J1 J2 | 2 | Keyed 2-pin power / I2C connector | JST | B2B-PH-K-S(LF)(SN) | PH 2.00 mm vertical THT | 0.5 | 1 | Estimate | Required | Through-hole bottom; quote THT assembly separately | https://www.jst-mfg.com/product/index.php?series=199 | 2026-09-06
J3 J4 | 2 | STEMMA QT / Qwiic socket | JST | SM04B-SRSS-TB(LF)(SN) | SH 1.00 mm horizontal SMT | 0.7 | 1.4 | Estimate | Required | SMT bottom; pin 1 GND, 2 3V3, 3 SDA, 4 SCL | https://www.jst-mfg.com/product/index.php?series=231 | 2026-09-06
J5 | 1 | PMSA003I paired mating socket | Supplied with module | Adafruit 4505 supplied socket | 2 x 5 1.27 mm SMT |  |  | Included in optional module kit | Optional PM | Consigned or hand-installed socket; verify land pattern against supplied part | https://www.adafruit.com/product/4505 | 2026-09-06

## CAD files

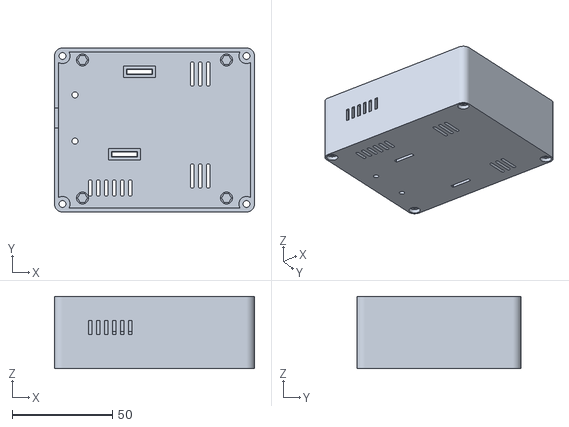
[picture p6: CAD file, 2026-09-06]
enclosure/stl/rear_full.stl
100.0 x 82.0 x 36.0

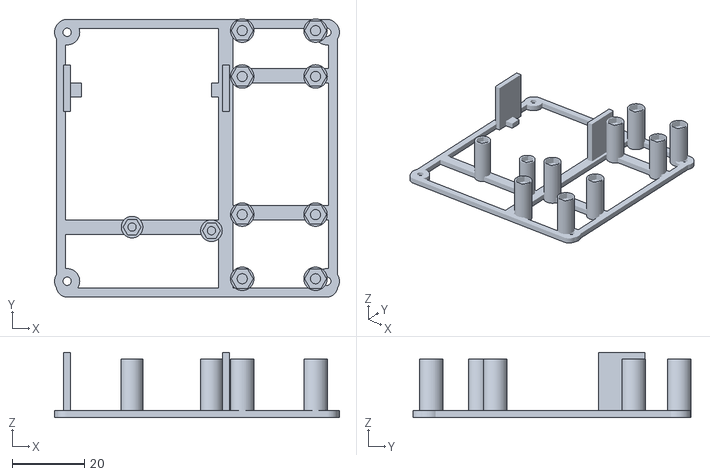
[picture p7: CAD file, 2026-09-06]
enclosure/stl/sensor_mount_full.stl
79.0 x 77.1 x 18.1

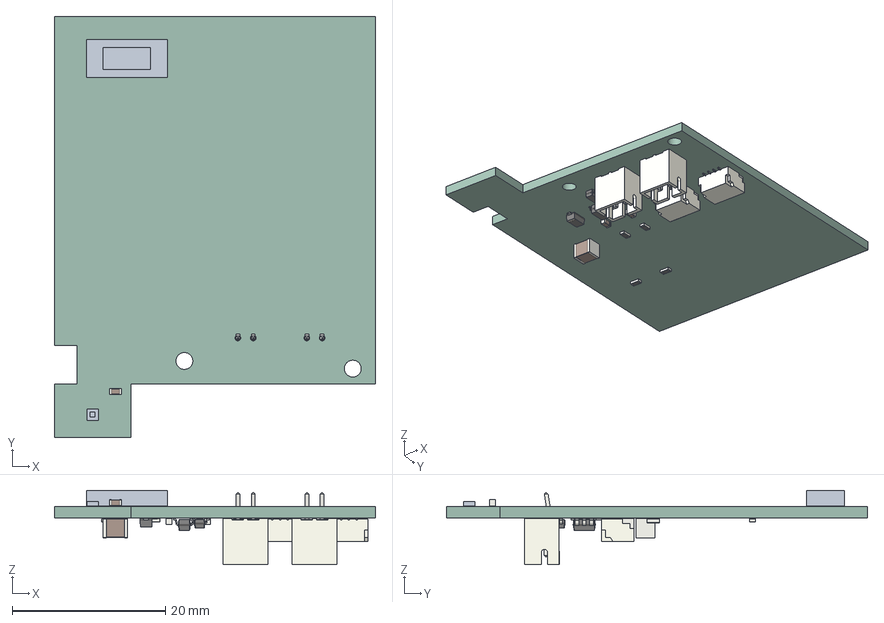
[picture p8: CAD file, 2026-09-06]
hardware/exports/airmon.step
42.0 x 55.0 x 9.68 mm
C_0603_1608Metric x 3
SOT-23-5
R_0603_1608Metric x 4
D_SOD_123F
Fuse_1206_3216Metric
SOT-23
JST_B2B_PH_K x 2
JST_SH_SM04B-SRSS-TB_1x04-1MP_P1.00mm_Horizontal x 2
C_1210_3225Metric
airmon_PCB

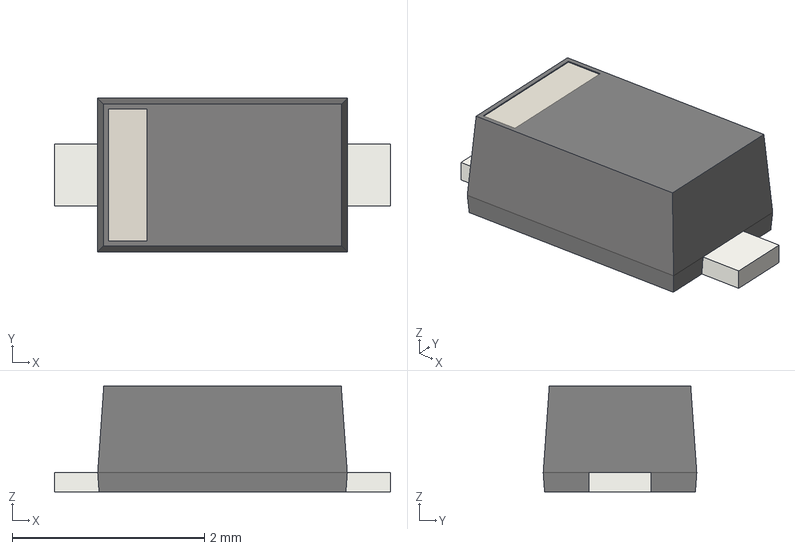
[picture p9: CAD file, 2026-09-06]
hardware/models/D_SOD-123F.step
3.50 x 1.60 x 1.10 mm

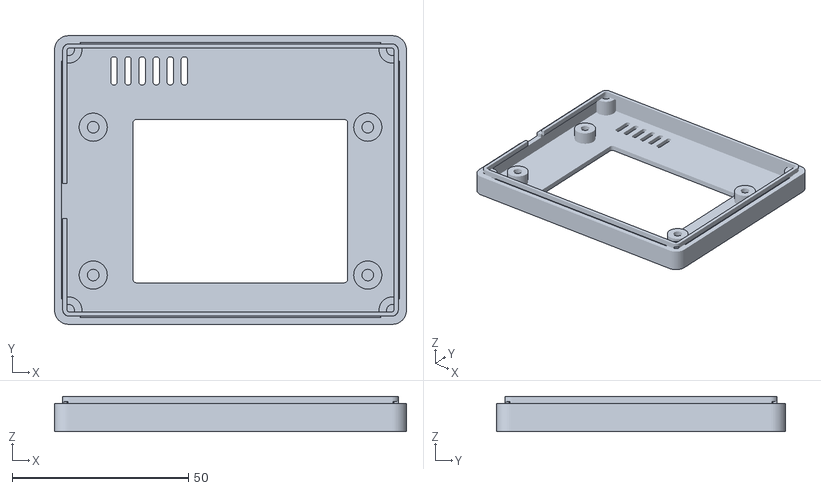
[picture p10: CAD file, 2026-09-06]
enclosure/stl/bezel.stl
100.0 x 82.0 x 10.0

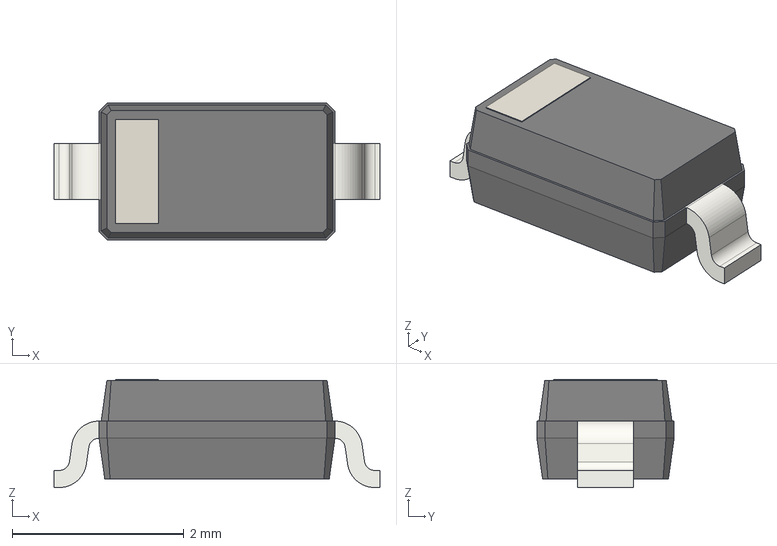
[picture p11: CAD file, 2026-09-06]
hardware/models/D_SOD-123.step
3.80 x 1.60 x 1.26 mm

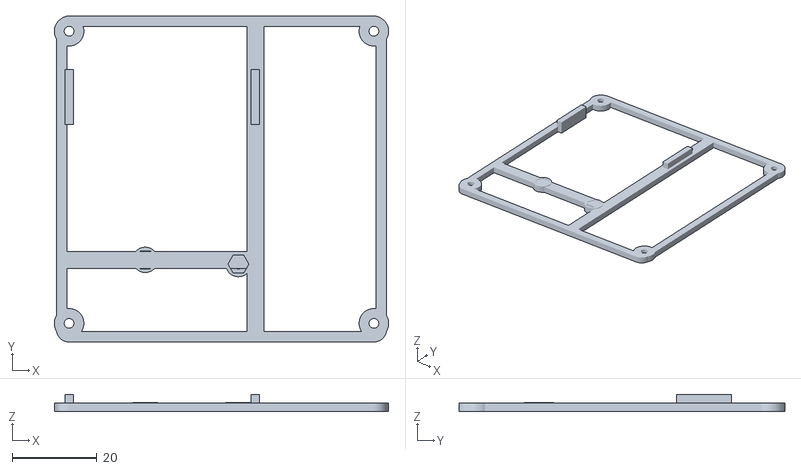
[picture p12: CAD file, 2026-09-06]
enclosure/stl/sensor_mount_shallow.stl
79.0 x 77.0 x 4.10

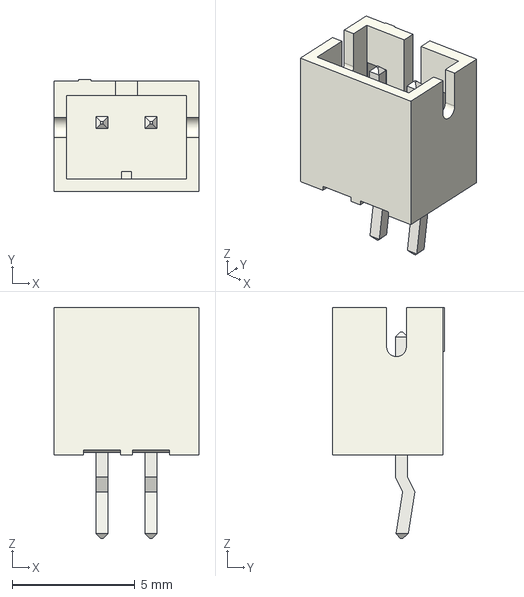
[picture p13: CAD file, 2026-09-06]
hardware/models/JST_PH_B2B-PH-K_1x02_P2.00mm_Vertical.step
5.90 x 4.55 x 9.40 mm

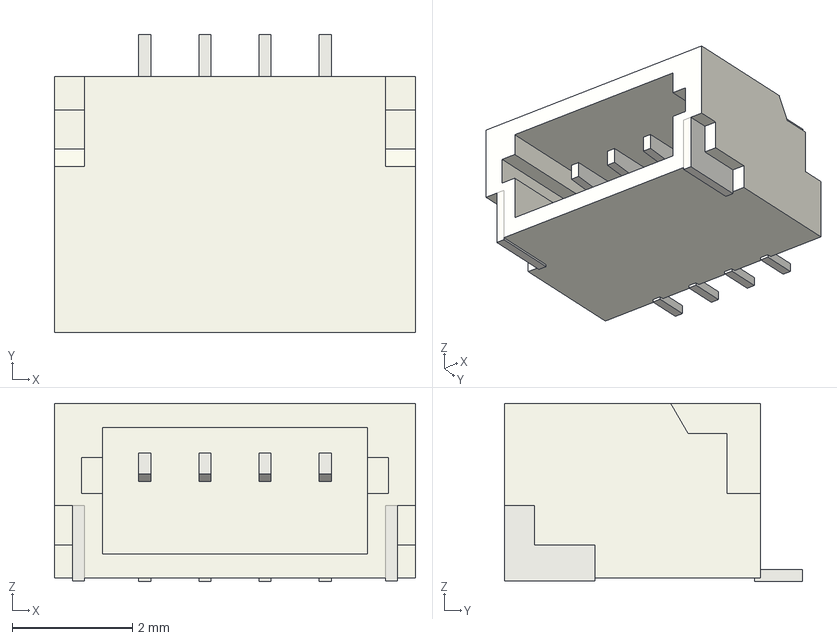
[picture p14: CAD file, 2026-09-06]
hardware/models/JST_SH_SM04B-SRSS-TB_1x04-1MP_P1.00mm_Horizontal.step
6.00 x 4.95 x 2.96 mm

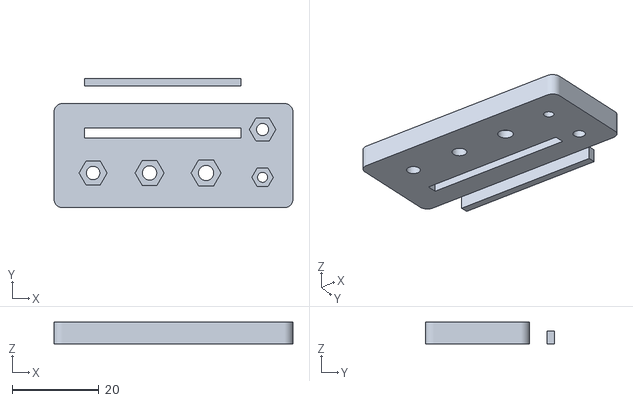
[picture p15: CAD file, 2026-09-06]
enclosure/stl/fit_test.stl
55.0 x 29.8 x 5.00

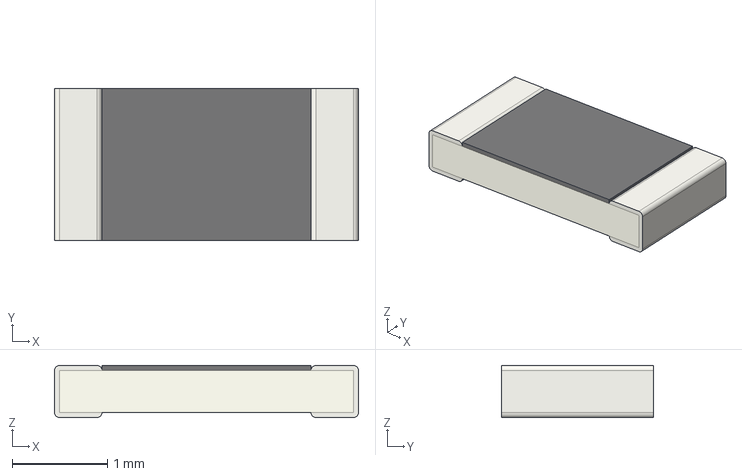
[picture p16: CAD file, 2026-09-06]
hardware/models/Fuse_1206_3216Metric.step
3.20 x 1.60 x 0.55 mm

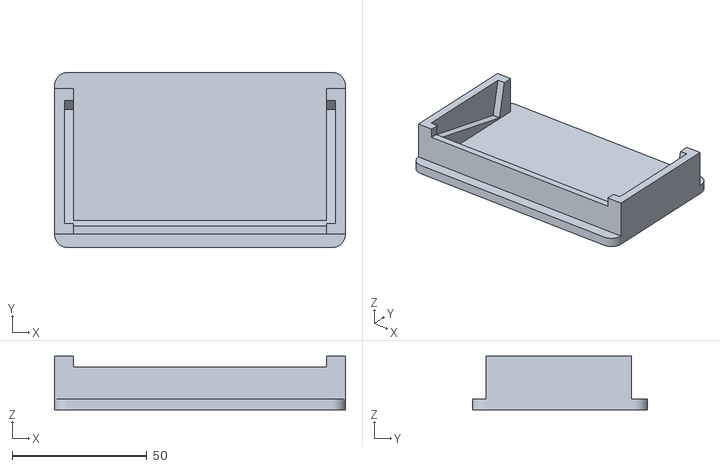
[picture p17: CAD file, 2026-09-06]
enclosure/stl/stand.stl
108.0 x 65.0 x 20.0

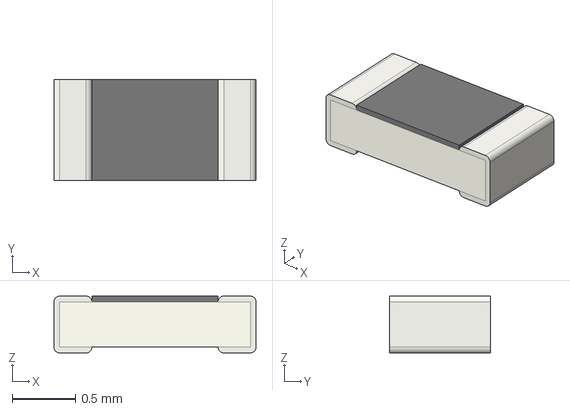
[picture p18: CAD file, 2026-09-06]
hardware/models/R_0603_1608Metric.step
1.60 x 0.8 x 0.45 mm

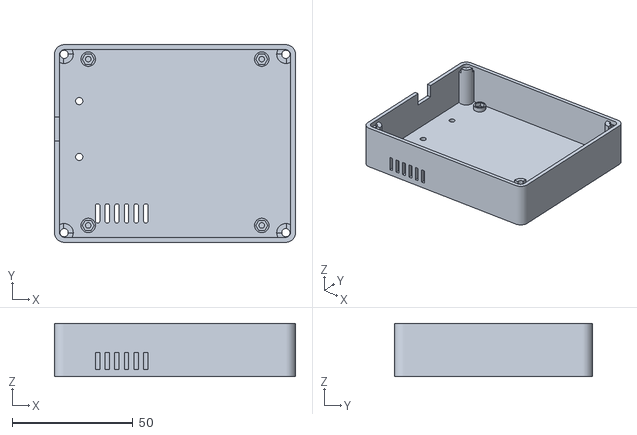
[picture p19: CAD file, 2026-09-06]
enclosure/stl/rear_shallow.stl
100.0 x 82.0 x 22.0

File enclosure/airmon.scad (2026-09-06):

/* AirMon parametric prototype. Units: mm.
   Mechanical source: LCDWIKI E32R28T drawing 2024-08-31.
   Module representations are clearance envelopes, not vendor detailed models.
   part: assembly, exploded, bezel, rear_full, rear_shallow, stand, fit_test, pcb
*/
part = "assembly";
full = true;
$fn = 48;
case_w=100; case_h=82;
wall=2; clearance=.3;
rear_depth=full ? 44 : 30;
pcb_z=6.6; sensor_z=22;
board_offset=[7,10];
carrier_offset=[15,15];
case_screws=[[4,4],[96,4],[4,78],[96,78]];
mount_screws=[[14,6],[86,6],[14,75],[86,75]];
board_holes=[[11,14],[89,14],[11,56],[89,56]];
carrier_holes=[[32,60],[54,61]];
sgp_origin=[60,3]; scd_origin=[60,54];

module rounded_plate(w,h,z,r=4) {
 linear_extrude(z) hull() for(x=[r,w-r],y=[r,h-r]) translate([x,y]) circle(r=r);
}
module ring(w,h,z,r=4,t=2) {
 difference(){rounded_plate(w,h,z,r);translate([t,t,-.01])rounded_plate(w-2*t,h-2*t,z+.02,max(.1,r-t));}
}
module bore(d,h) {cylinder(d=d,h=h);}
module hex_nut(flat,h) {cylinder(d=flat/cos(30),h=h,$fn=6);}
module bezel() {
 difference() {
  union() {
   difference(){rounded_plate(case_w,case_h,2);translate([22.3,11.8,-.1])rounded_plate(61,46.4,2.2,1);}
   ring(case_w,case_h,8);
   translate([2.3,2.3,8])ring(95.4,77.4,2,2,1.2);
   for(p=board_holes)translate([p[0],p[1],2])cylinder(d=8,h=pcb_z-2);
   for(p=case_screws)translate([p[0],p[1],0])cylinder(d=7.6,h=8);
  }
  for(p=board_holes) {
   translate([p[0],p[1],2.15])hex_nut(5.8,2.7);
   translate([p[0],p[1],2])bore(3.3,6);
  }
  for(p=case_screws) {
   translate([p[0],p[1],2.6])hex_nut(5.8,2.7);
   translate([p[0],p[1],2.6])bore(3.3,6);
  }
  // USB plug access continues through the shell seam.
  translate([-.1,30,6.5])cube([8,10,8]);
  // Front room-air vents below the display, separated from its heat sources.
  for(x=[16:4:36])translate([x,68,-.1])rounded_plate(1.8,8,2.2,.8);
  translate([64,75,.49])rotate([180,0,0])linear_extrude(.5)text("AirMon",size=5,halign="center",font="Liberation Sans:style=Bold");
 }
}
module rear_post(p,d=6,flat=4.3,hole=2.3,depth=rear_depth,nut_h=1.9) {
 difference() {
  translate([p[0],p[1],sensor_z+1.6])cylinder(d=d,h=depth-sensor_z-1.6);
  translate([p[0],p[1],sensor_z+1.58])hex_nut(flat,nut_h);
  translate([p[0],p[1],sensor_z+1.5])bore(hole,7);
 }
}
module rear(is_full=full) {
 rear_depth=is_full?44:30;
 difference() {
  union() {
   translate([0,0,8])ring(case_w,case_h,rear_depth-8);
   translate([0,0,rear_depth-wall])rounded_plate(case_w,case_h,wall);
   for(p=case_screws)translate([p[0],p[1],8])cylinder(d=7.6,h=rear_depth-8);
   for(p=mount_screws)difference() {
    translate([p[0],p[1],rear_depth-4.2])cylinder(d=6,h=4.2);
    translate([p[0],p[1],rear_depth-4.21])hex_nut(4.3,1.9);
    translate([p[0],p[1],rear_depth-4.21])bore(2.3,4.3);
   }
   if(is_full) {
    // Independent inlet/outlet ducts, sealed to the module face with thin foam.
    difference() {
     translate([34.5,9,25.6])cube([16,5.7,18.4]);
     translate([36,10.5,25.5])cube([13,2.7,17]);
     translate([35.5,12.9,26.6])cube([13,2,6]);
    }
    difference() {
     translate([27,50.3,25.6])cube([16,5.7,18.4]);
     translate([28.5,51.8,25.5])cube([13,2.7,17]);
     translate([28.5,50.2,26.6])cube([13,2,5]);
    }
   }
  }
  for(p=case_screws) {
   translate([p[0],p[1],7.9])bore(3.4,rear_depth);
   translate([p[0],p[1],rear_depth-2.2])bore(6.2,2.3);
  }
  // Relief around the alignment tongue, including the corner screw bosses.
  translate([2,2,7.9])ring(96,78,2.4,2.3,1.8);
  // Physical BOOT/RESET access from the back; use a nonconductive probe.
  for(y=[23.43,46.57])translate([10.26,y,rear_depth-3])bore(3,4);
  translate([-.1,30,6.5])cube([8,10,8]);
  // SHT40 vents in the lower wall and rear; avoid a copper/metal heat path.
  for(x=[17:4:37])translate([x,66,rear_depth-2.1])rounded_plate(1.8,8,2.2,.8);
  for(x=[17:4:37])translate([x,case_h-2.1,20])cube([1.8,2.2,7]);
  if(is_full) {
   // Opposite PM edges: inlet near y=15, outlet near y=50.
   translate([36.3,10.8,rear_depth-2.1])rounded_plate(12.4,2.1,2.2,.4);
   translate([28.8,52.1,rear_depth-2.1])rounded_plate(12.4,2.1,2.2,.4);
   for(origin=[sgp_origin,scd_origin])for(x=[8:4:16])translate([origin[0]+x,origin[1]+4,rear_depth-2.1])rounded_plate(1.8,12,2.2,.8);
  }
 }
}
module sensor_mount(is_full=full) {
 top=is_full?39.8:25.8;
 difference() {
  union() {
   translate([11,2.4,top-2])ring(78,77,2,3,2.5);
   translate([56,2.4,top-2])cube([4,77,2]);
   translate([11,58,top-2])cube([49,4,2]);
   for(p=mount_screws)translate([p[0],p[1],top-2])cylinder(d=7,h=2);
   for(p=carrier_holes)rear_post(p,depth=top);
   for(x=[13,57])translate([x,15,21.7])cube([2,13,top-21.7]);
   if(is_full) {
    for(y=[16,54])translate([58,y,top-2])cube([31,4,2]);
    for(x=[2.54,22.86],y=[2.54,15.24])rear_post([sgp_origin[0]+x,sgp_origin[1]+y],6.5,5.3,2.8,top,2.3);
    for(x=[2.54,22.86],y=[2.54,20.32])rear_post([scd_origin[0]+x,scd_origin[1]+y],6.5,5.3,2.8,top,2.3);
    // Retaining lips touch thin foam over the PM body, clear of both air ports.
    for(x=[13,54])translate([x,20,37.8])cube([5,4,2]);
   }
  }
  for(p=mount_screws)translate([p[0],p[1],top-2.1])bore(2.3,2.2);
 }
}
module carrier() {
 color("#24795c")translate([carrier_offset[0],carrier_offset[1],sensor_z])linear_extrude(1.6)
 difference() {
  polygon([[0,0],[42,0],[42,48],[10,48],[10,55],[0,55],[0,48],[3,48],[3,43],[0,43]]);
  for(p=[[17,45],[39,46]])translate(p)circle(d=2.2);
 }
 color("#22282c")translate([carrier_offset[0]+4.23,carrier_offset[1]+2,sensor_z+1.6])cube([10.54,7,2]);
 color("#ddd9ca")translate([carrier_offset[0]+4.25,carrier_offset[1]+51.25,sensor_z+1.6])cube([1.5,1.5,.55]);
 // Connector and regulator clearance envelopes on the underside.
 color("#ede8db")for(p=[[26,42],[35,42]])translate([carrier_offset[0]+p[0]-5,carrier_offset[1]+p[1]-3,sensor_z-6])cube([8,6,6]);
 color("#ede8db")for(x=[29,38])translate([carrier_offset[0]+x-3,carrier_offset[1]+32,sensor_z-3])cube([6,4,3]);
 color("#262b32")translate([carrier_offset[0]+15.5,carrier_offset[1]+35.5,sensor_z-1.2])cube([3,3,1.2]);
}
module pm_module() {
 color("#bbc1c7")difference() {
  translate([17,15,25.6])cube([38,35,12]);
  translate([36.5,14.9,27.6])cube([10,2,4]);
  translate([29,48.5,27.6])cube([10.5,2,3]);
 }
 color("#313c44")translate([36.5,15,27.6])cube([10,.2,4]);
 color("#596873")translate([36,35,37.61])linear_extrude(.05)text("PMSA003I",size=3,halign="center");
}
module gas_module(origin,kind="scd") {
 h=kind=="scd"?22.86:17.78;
 color("#27374b")translate([origin[0],origin[1],sensor_z])linear_extrude(1.6)
 difference() {square([25.4,h]);for(x=[2.54,22.86],y=[2.54,h-2.54])translate([x,y])circle(d=2.8);}
 if(kind=="scd")color("#d3c9a7")translate([origin[0]+6,origin[1]+4,sensor_z+1.6])cube([11,11,7]);
 else color("#b6a998")translate([origin[0]+10,origin[1]+6,sensor_z+1.6])cube([3,3,1]);
 color("#ede8db")for(x=[0,21])translate([origin[0]+x,origin[1]+h/2-2,sensor_z+1.6])cube([4,4,3]);
}
module display_board() {
 color("#a8a534")translate([7,10,pcb_z])linear_extrude(1.6)difference(){square([86,50]);for(x=[4,82],y=[4,46])translate([x,y])circle(d=3.2);}
 color("#252c31")translate([15.4,10,2.6])cube([69.2,50,4]);
 color("#0e202c")translate([24.1,13.4,2.54])cube([57.6,43.2,.06]);
 color("#bcc5c8")translate([74,25,pcb_z+1.6])cube([13,18,3]);
 color("#2c3336")translate([87,25,pcb_z+1.6])cube([6,18,1]);
 color("#b7bec6")translate([6.5,31,pcb_z+1.6])cube([7,8,3]);
 // Illustrative LCD values; not a screenshot of the physical firmware.
 for(i=[0:3]) {
  color("#97b7c4")translate([28,20+i*8,2.50])rotate([180,0,0])linear_extrude(.04)text(["AIRMON","22.4 C   45 %","PM2.5   8","CO2   620"][i],size=i==0?3:2.6,font="Liberation Sans");
 }
}
module pose() {translate([4,8,14])rotate([-102,0,0])translate([0,-case_h,0])children();}
module stand() {
 difference() {
  union() {
   rounded_plate(108,65,4,5);
   for(x=[0,101])translate([x,5,0])cube([7,54,20]);
   translate([3,5,0])cube([102,5,16]);
  }
  pose()translate([-.35,-.35,-.35])cube([case_w+.7,case_h+.7,44.7]);
 }
}
module fit_test() {
 difference(){rounded_plate(55,24,5,2);
  for(i=[0:2])translate([9+i*13,8,1.9])hex_nut(5.6+.2*i,3.2);
  for(i=[0:2])translate([9+i*13,8,-.1])bore(3.1+.2*i,5.2);
  translate([7,16,-.1])cube([36,2.4,5.2]);
  translate([48,7,3.1])hex_nut(4.3,2);
  translate([48,7,-.1])bore(2.3,5.2);
  translate([48,18,2.7])hex_nut(5.3,2.4);
  translate([48,18,-.1])bore(2.8,5.2);
 }
 translate([7,28,0])cube([36,1.8,3]);
}
module exploded() {
 color("#344e58")translate([-4,8.5,-50])stand();
 color("#e4e0d5")translate([0,0,-20])bezel();
 display_board();
 translate([0,0,20])carrier();
 if(full){translate([0,0,36])pm_module();translate([0,0,20])gas_module(scd_origin);translate([0,0,20])gas_module(sgp_origin,"sgp");}
 color("#d3ad73")translate([0,0,55])sensor_mount();
 color("#3e5962")translate([20,10,120])rear();
}
if(part=="bezel")bezel();
else if(part=="rear_full")translate([0,case_h,44])rotate([180,0,0])rear(true);
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

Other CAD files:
hardware/models/C_1210_3225Metric.step
hardware/models/SOT-23.step
hardware/models/Sensirion_DFN-4_1.5x1.5mm_P0.8mm_SHT4x_NoCentralPad.step
hardware/models/PMSA003I_SuppliedSocket.step
hardware/models/C_0603_1608Metric.step
hardware/models/SOT-23-5.step

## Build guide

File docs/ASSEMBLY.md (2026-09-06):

# Printing and assembly

This is an illustrated prototype assembly procedure. Check the purchased display board and PM socket against the drawings before ordering the carrier. Do not force a connector or use enclosure screws to pull misaligned parts together.

## Assembly view

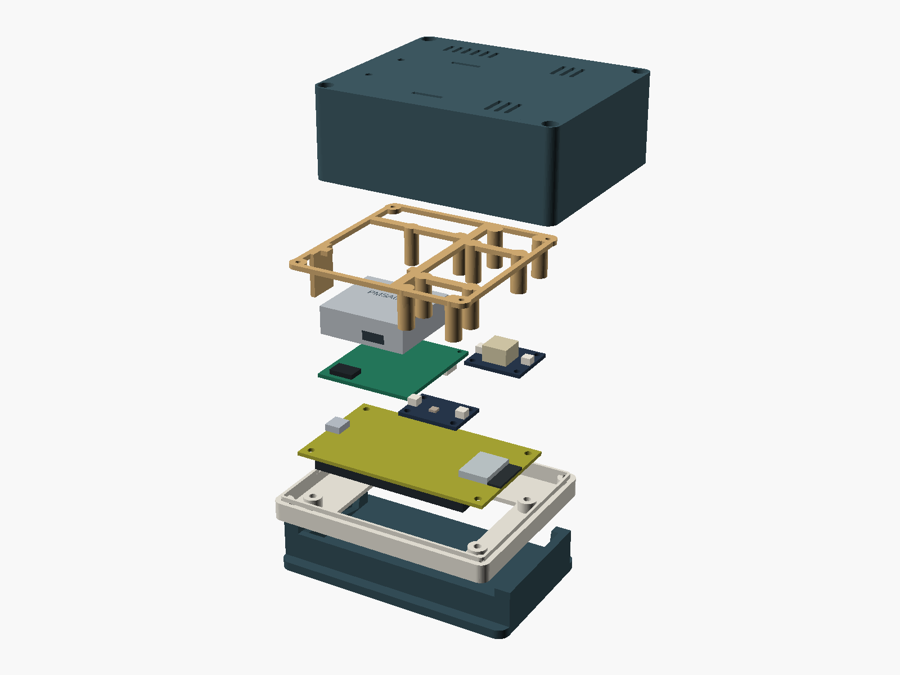
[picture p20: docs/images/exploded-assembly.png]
Exploded full-sensor AirMon assembly


From bottom to top: desktop stand, front bezel, Keyestudio display board, sensor carrier and gas breakouts, PMSA003I module, removable sensor frame, and rear shell. The display and sensor modules are simplified dimensional models. Cables, screws, and foam are omitted for clarity; their routing and compression need a physical prototype check.

Completed enclosure

The screen faces forward with a 12° recline in the stand. Printed colors are a suggestion. The illustrated LCD text is not a capture of the running firmware.

## Choose a shell

| Build | Print once each | Case fasteners |
|---|---|---|
| SHT40 only | `bezel`, `rear_shallow`, `sensor_mount_shallow`, `stand`, `fit_test` | Four M3 × 25 mm screws |
| Any optional sensor, including PM only | `bezel`, `rear_full`, `sensor_mount_full`, `stand`, `fit_test` | Four M3 × 40 mm screws; two 0.5 mm DIN 433 washers under each head |

The shared bezel is 100 × 82 mm. Installed full depth is 44 mm; shallow depth is 30 mm. The stand footprint is 108 × 65 mm. STLs already have their intended print orientation and use millimetres. Do not scale parts to make them fit a printer.

## Print settings

Start with PLA, a 0.4 mm nozzle, 0.2 mm layers, four walls, five top/bottom layers, 15% gyroid infill, and supports disabled. Use your filament manufacturer's temperature and bed settings. A brim is optional for adhesion; trim it fully from mating surfaces. The geometry is intended for support-free printing, but nut-pocket bridges and the enclosure fit still need a print test on your machine.

| Part | Face on build plate | Check after printing |
|---|---|---|
| Bezel | Flat outside/front face | Touch opening, captive M3 pockets, alignment tongue |
| Rear shell | Flat outside/back face | Open vents, unobstructed ducts, screw bores |
| Sensor frame | Broad ring face, as exported | Straight posts, captive M2/M2.5 pockets |
| Stand | Flat bottom | No rocking; case slides into cradle |
| Fit coupon | Broad flat face, as exported | Two bodies are intentional: coupon and mating strip |

Print the coupon first. Its three M3 holes are 3.1/3.3/3.5 mm, with nut pockets 5.6/5.8/6.0 mm across flats. The design uses the middle option. The separate strip checks nominal 0.3 mm clearance per side. Two additional pockets check the M2 and M2.5 nuts. Nuts should seat without splitting PLA. Adjust the OpenSCAD dimensions if your printer cannot reproduce these fits; regenerate and re-check all affected parts.

## Assemble the electronics

1. Inspect the carrier for solder bridges, correct U1/Q1/D1 orientation, and an unobstructed SHT40 opening. Avoid touching, washing, or coating the sensor on the small tongue.
2. Fit J1/J2 through-hole connectors if the assembly service did not install them. For PM support, install the **socket supplied with the PMSA003I kit** at J5. Check its pad map and orientation before soldering. This one-time step is required if J5 was omitted from PCBA assembly; subsequent PM installation is plug-in.
3. Build and continuity-check both harnesses using the [pin-to-pin table](HARDWARE.md#harnesses). Both carrier connectors have the same housing, so label them **POWER** and **I2C** at both ends. Interchanging them can apply 5 V to a signal pin.
4. Perform the unloaded and loaded rail checks in [hardware validation](HARDWARE.md#first-power-checks) before installing all modules.

## Fit the enclosure

1. With USB disconnected, insert four M3 display nuts and four M3 closure nuts into the bezel pockets. Remove stray plastic; avoid glue near sensor air paths.
2. Place the display face down into the bezel and use four M3 × 6 mm screws through its mounting holes. Tighten gently and evenly. The bezel should bear on its mounting posts, with clearance around the resistive panel. Check touch operation again after assembly.
3. Insert two M2 carrier nuts into the sensor frame posts. Add M2.5 nuts for installed gas modules. Slide the carrier's upper edge into the guides, with the SHT40 tongue pointing toward the lower room-air vents. Secure its two holes using M2 × 5 mm screws from the underside.
4. If using PM, seat the module straight onto J5 without loading the socket sideways. The frame lips retain the metal body. Apply thin foam under the retaining lips only if needed; never cover a port or crush the module.
5. Attach SCD40 and/or SGP41 to their matching four-hole mounts with M2.5 × 6 mm screws. In assembly coordinates the SGP41 is at the upper right and SCD40 at the lower right. Use one 100 mm QT cable from J3/J4 to each module; either socket can serve either module.
6. Route power and I²C harnesses toward the USB side and QT cables around the frame. Secure slack with cable ties through frame openings, leaving room to unplug connectors. Keep wires clear of the ESP32 antenna at the display board's right edge, vents, PM ports, and SHT40 tongue.
7. For PM, fit 0.5 mm foam around the two duct interfaces. Trim it to bridge the nominal 0.3 mm gap without obstructing intake or exhaust. Do not join the separate ducts with a common foam cavity. Confirm the actual module ports align before closing.
8. Insert four M2 nuts into the rear-shell frame anchors. Fit the populated sensor frame to the rear shell with four M2 × 6 mm screws. Check that wires can flex in the display-to-carrier gap without pressing on components. The CAD check leaves approximately 2.6 mm above the modeled rear display components; connector exits need a physical check.
9. Connect the labeled harnesses, close the shell on the alignment tongue, and use the correct four case screws. On the full shell, the two specified washers per screw set the thread depth. Stop if a screw bottoms out before the shell closes.
10. Add four feet beneath the stand and slide the unit into it. Check stability, USB clearance, and unobstructed air openings. BOOT/RESET are accessible through rear probe holes; use a nonconductive probe.

## Verify before routine use

Run the [physical acceptance procedure](VALIDATION.md#physical-acceptance-procedure). Compare temperature against a separate reference after thermal equilibrium, both with and without optional modules. An offset cannot correct an error that changes with brightness, airflow, or sensor loading; revise placement or isolation if necessary.

Unplug USB before adding or removing modules. Use the full shell and frame for any upgrade. Firmware auto-detects supported I²C addresses. Keep the microSD slot empty in every configuration.

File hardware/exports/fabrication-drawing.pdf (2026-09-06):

# AirMon / Carrier fabrication drawing

Prototype r0.1 | 2026-09-06 | Dimensions in mm; do not scale drawing

HOLD: verify supplied PM socket and exact display-board harness before fabrication.

TOP VIEW

Origin: upper-left corner
+X right; +Y down

2 x 2.20 mm NPTH
Hole centres:
(17.00, 45.00)
(39.00, 46.00)

Main body: 42.00 x 48.00
Tongue: 10.00 x 7.00
Left neck notch: 3.00 x 5.00

42.00

55.00

10.00

## Fabrication and assembly notes

2 copper layers; FR-4; finished board thickness 1.60 mm; 1 oz copper.
Solder mask both sides; lead-free finish; no controlled impedance requirement. Minimum designed track width 0.25 mm; clearance 0.20 mm.
Through vias: 0.30 mm drill / 0.60 mm copper diameter. No via-in-pad.
Follow Gerber outline and Excellon files for complete machining geometry. Non-dimensioned tolerances: confirm manufacturer standard capability before order. Assemble both sides using drawings, BOM, and placement CSV; check bottom rotation. J1/J2 through-hole assembly is separate from SMT; J5 supplied socket is optional. Keep SHT40 aperture free of flux contamination, wash, adhesive, and coating.
No production approval implied: electrical load, thermal behavior, and fit tests pending.

Source of truth: hardware/airmon.kicad_pcb and hardware/exports/airmon-gerbers.zip See docs/HARDWARE.md for harness pinout and prototype release gates.

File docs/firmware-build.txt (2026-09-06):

ESP-IDF v5.5.1 / classic ESP32 / 4 MB / prototype build
2026-09-06

Memory Type Usage Summary
┏━━━━━━━━━━━━━━━━━━━┳━━━━━━━━━━━━━━┳━━━━━━━━━━┳━━━━━━━━━━━━━━━━┳━━━━━━━━━━━━━━━┓
┃ Memory            ┃              ┃          ┃                ┃               ┃
┃ Type/Section      ┃ Used [bytes] ┃ Used [%] ┃ Remain [bytes] ┃ Total [bytes] ┃
┡━━━━━━━━━━━━━━━━━━━╇━━━━━━━━━━━━━━╇━━━━━━━━━━╇━━━━━━━━━━━━━━━━╇━━━━━━━━━━━━━━━┩
│ Flash Code        │       918536 │          │                │               │
│    .text          │       918536 │          │                │               │
│ Flash Data        │       292080 │          │                │               │
│    .rodata        │       291824 │          │                │               │
│    .appdesc       │          256 │          │                │               │
│ DRAM              │       146036 │     80.8 │          34700 │        180736 │
│    .bss           │       129520 │    71.66 │                │               │
│    .data          │        16516 │     9.14 │                │               │
│ IRAM              │        99391 │    75.83 │          31681 │        131072 │
│    .text          │        98363 │    75.05 │                │               │
│    .vectors       │         1028 │     0.78 │                │               │
│ RTC SLOW          │           56 │     0.68 │           8136 │          8192 │
│    .force_slow    │           32 │     0.39 │                │               │
│    .rtc_slow_rese │           24 │     0.29 │                │               │
│ rved              │              │          │                │               │
└───────────────────┴──────────────┴──────────┴────────────────┴───────────────┘
Total image size: 1326555 bytes (.bin may be padded larger)
Note: The reported total sizes may be smaller than those in the technical
reference manual due to reserved memory and application configuration. The total
flash size available for the application is not included by default, as it
cannot be reliably determined due to the presence of other data like the
bootloader, partition table, and application partition size.

Physical execution not verified; see VALIDATION.md.

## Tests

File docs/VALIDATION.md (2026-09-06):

# Requirements and validation ledger

**Prototype r0.1, 2026-09-06. No physical prototype has been tested.** The digital deliverables are provided for review and prototype preparation. Production/manufacturing approval remains withheld pending purchased-part and physical checks.

## Completed digital checks

| Area | Evidence | Result and limit |
|---|---|---|
| PCB electrical rules | [erc.txt](../hardware/exports/erc.txt) | 0 violations |
| PCB layout rules | [drc.txt](../hardware/exports/drc.txt) | 0 violations, 0 unconnected items |
| Schematic/PCB consistency | [netlist-validation.json](../hardware/exports/netlist-validation.json) | All 56 connected pads agree across 9 nets; 519 tracks, 60 vias |
| Manufacturing exports | [exports](../hardware/exports/) | Gerber/drill ZIP, placement CSVs, schematic/assembly/fabrication PDFs, 1:1 footprint print, and STEP generated; drawings visually inspected |
| BOM | [BOM.xlsx](../hardware/BOM.xlsx), two CSVs | Required/optional classifications, sources, estimates, and unknown quotes distinguished; workbook formula scan found no errors |
| Mesh topology | [mesh-validation.json](../enclosure/mesh-validation.json) | 7 watertight STLs; consistent winding, correct body counts, positive print-bed placement |
| Full CAD assembly | [clearance-validation.json](../enclosure/clearance-validation.json) | 28 solid-pair checks, no overlapping volume above 0.01 mm³ |
| Shallow CAD assembly | [clearance-validation-shallow.json](../enclosure/clearance-validation-shallow.json) | 10 solid-pair checks, same tolerance |
| Reference slicing | [slicing-validation.json](../enclosure/slicing-validation.json) | All 7 parts sliced successfully with no slicer warning strings; 0.4 mm nozzle, 0.2 mm layers, 4 walls, 15% gyroid, supports disabled |
| Documentation renders | [images](images/) and [assembly guide](ASSEMBLY.md) | Native PCB top/underside, PCB with PM, completed enclosure, exploded assembly; CAD/illustrative-screen limitations captioned |
| ESP32 compilation | [build report](firmware-build.txt), [manifest](../release/firmware/manifest.json) | Successful ESP-IDF v5.5.1 build; about 33% free in each OTA slot; runtime memory/load tests pending |
| Portable firmware logic | `scripts/test_core.sh` | ASan/UBSan pass: CRC/checksum, corrupt frames, PM field selection, freshness/nulls, history means/gaps/rollover, touch transform, token comparison, strict unsigned history-query parsing |
| Configuration logic | `scripts/test_config.sh` | ASan/UBSan pass using actual config.c with transactional NVS fake: limits, password redaction, credential/touch persistence, failed-commit preservation |
| Embedded web UI | [web-validation.json](web-validation.json) | 10 checks in isolated Chrome with simulated HTTP API; desktop/mobile layout, pagination, auth errors, password semantics, offline state, no uncaught JS errors |

Slicing is a reference-printer computation, not a physical print. Collision checks use the actual KiCad STEP carrier and simplified display/module envelopes; screws, cables, foam, and manufacturing tolerances are not validated solids. The firmware host/browser tests do not emulate physical I²C, ESP32 Wi-Fi, the HTTP server, NVS flash, TLS allocation, or OTA flash writes.

## Remaining release gates

| Requirement | What is still required |
|---|---|
| Exact display and harness | Match delivered E32R28T PCB; identify board-side connector housing/contact MPN or obtain confirmed mating pigtails; verify numbered conductors |
| PM socket | Compare supplied socket to 1:1 land pattern, confirm Plantower mating pin map, measure mating height and actual port alignment |
| BOM completeness for ordering | Resolve the two board-side connector housings/contacts and socket sourcing/consignment; obtain PCB/PCBA/harness quotes |
| Electrical behavior | Power startup, USB/Q5 drop, 5 V and 3.3 V rail minima, current, LDO temperature, I²C LOW voltage/rise time for all eight module combinations |
| Mechanical behavior | Fit coupon, print bridges, nut retention, touchscreen edge clearance, cable bend/strain relief, antenna placement, duct foam seal, service access, stand stability |
| Device UI and drivers | Actual LCD colors/orientation, touch calibration and BOOT, real sensor readings, failure/recovery and warmup timings |
| Provisioning | Successful/failed Wi-Fi changes, router outage/reboot, NVS persistence after power loss, AP reentry and closure |
| API | Real ESP32 HTTP positive/negative requests, simultaneous readers, history pagination over reboot, auth and body limits |
| MQTT/Home Assistant | Broker integration, discovery, per-metric availability, last will, broker/router restarts, TLS memory stress |
| OTA | Incompatible image, interrupted upload/write, new-image crash/rollback, preserved settings, successful USB recovery |
| Long run and ambient accuracy | Fully populated 24-hour run, minimum free heap, resets/error counts, calibrated temperature reference at multiple brightness/load conditions |

The costly sensors remain optional. A later PM upgrade is plug-in only if its socket was installed initially; otherwise that upgrade includes one soldering step. This procurement limitation is documented rather than hidden in the optionality claim.

## Physical acceptance procedure

Record board revision, module revisions, firmware manifest hash, printer/filament, ambient conditions, date, and instrument models before testing. Do not mark a row passed without measured evidence.

1. **Unpowered inspection:** Verify harness continuity, labels and no shorts. Match both supplied connectors to drawings. Confirm pin 1 and module port orientations.
2. **Fit coupon and enclosure:** Print the coupon before full parts. Verify captive nuts and alignment strip. Assemble gently; test touch across all corners with the shell open and closed. Check access to USB/BOOT/RESET and remove/reinstall the sensor frame.
3. **Electrical matrix:** For each PM/CO₂/SGP41 on/off combination, unplug USB before changing modules. Record steady and startup current, minimum SENSOR5V/SENSOR3V3, LDO temperature, and I²C rise/LOW measurements. PM input must remain 4.5–5.5 V; target carrier 3.3 V ±5%. Confirm the red LED/GPIO22 supply behavior. Keep SD empty.
4. **Driver behavior:** Confirm supported addresses and fresh readings. With power removed, disconnect one sensor and reboot: other metrics must continue, absent values must be null. Reconnect and verify detection. Use a controllable I²C test fixture for corrupt-response and held-bus tests; never short a powered supply.
5. **Wi-Fi/API:** Provision correct credentials, then attempt incorrect ones and confirm old configuration returns. Cycle the router. Reopen AP with BOOT. Verify GET reads, rejected unauthenticated writes, valid configuration, oversized JSON, and concurrent history reads.
6. **MQTT:** Observe retained discovery and unavailable missing sensors. Restart Home Assistant and the broker. Remove Wi-Fi temporarily and confirm availability expires; reconnect and confirm recovery. Repeat with MQTT TLS enabled while monitoring minimum heap.
7. **OTA/recovery:** Save a known-good USB bundle. Try a wrong-chip image and an interrupted HTTP transfer; verify the current image still boots. On a sacrificial prototype, interrupt flash programming and test a deliberately crashing new image to verify rollback. Confirm all settings survive successful OTA. Demonstrate BOOT/RESET USB recovery.
8. **Thermal/24-hour run:** Place an independent temperature reference near the inlet, clear of exhaust. Compare after equilibrium at 5%, 30%, and 100% brightness with optional modules absent and present. Record changing bias; redesign airflow/isolation if an offset is insufficient. Run fully populated for 24 hours with charts and MQTT active. Record uptime, minimum heap, error counters, reset history, rail minima, and sample continuity.
9. **Release decision:** Resolve connector/BOM unknowns, attach measurements and photos, update models/firmware as required, rerun affected digital checks, and only then remove the prototype hold.

## Test record template

| Date / configuration | Instrument / method | Measurement / observation | Pass criterion | Result |
|---|---|---|---|---|
| Pending | Pending | Pending | As specified above | Not tested |

The private GitHub repository is `lordkev/airmon`. Commits containing these files are prototype checkpoints, not evidence of physical acceptance.

## Follow-up validation preparation

- History query parsing now rejects malformed decimal values, signed inputs, fractions, overflow, and truncated query strings. Core sanitizer tests cover these boundaries.
- Touch recalibration requests are transferred atomically to the display task, preventing a concurrent request from being cleared by the consumer. Physical touchscreen validation remains pending.
- `scripts/test_device_api.py` provides read-only acceptance checks against an actual device. It has not been run against hardware because no ESP32 serial device or AirMon network address is available. Run it after first provisioning and retain its JSON report with the physical test record.

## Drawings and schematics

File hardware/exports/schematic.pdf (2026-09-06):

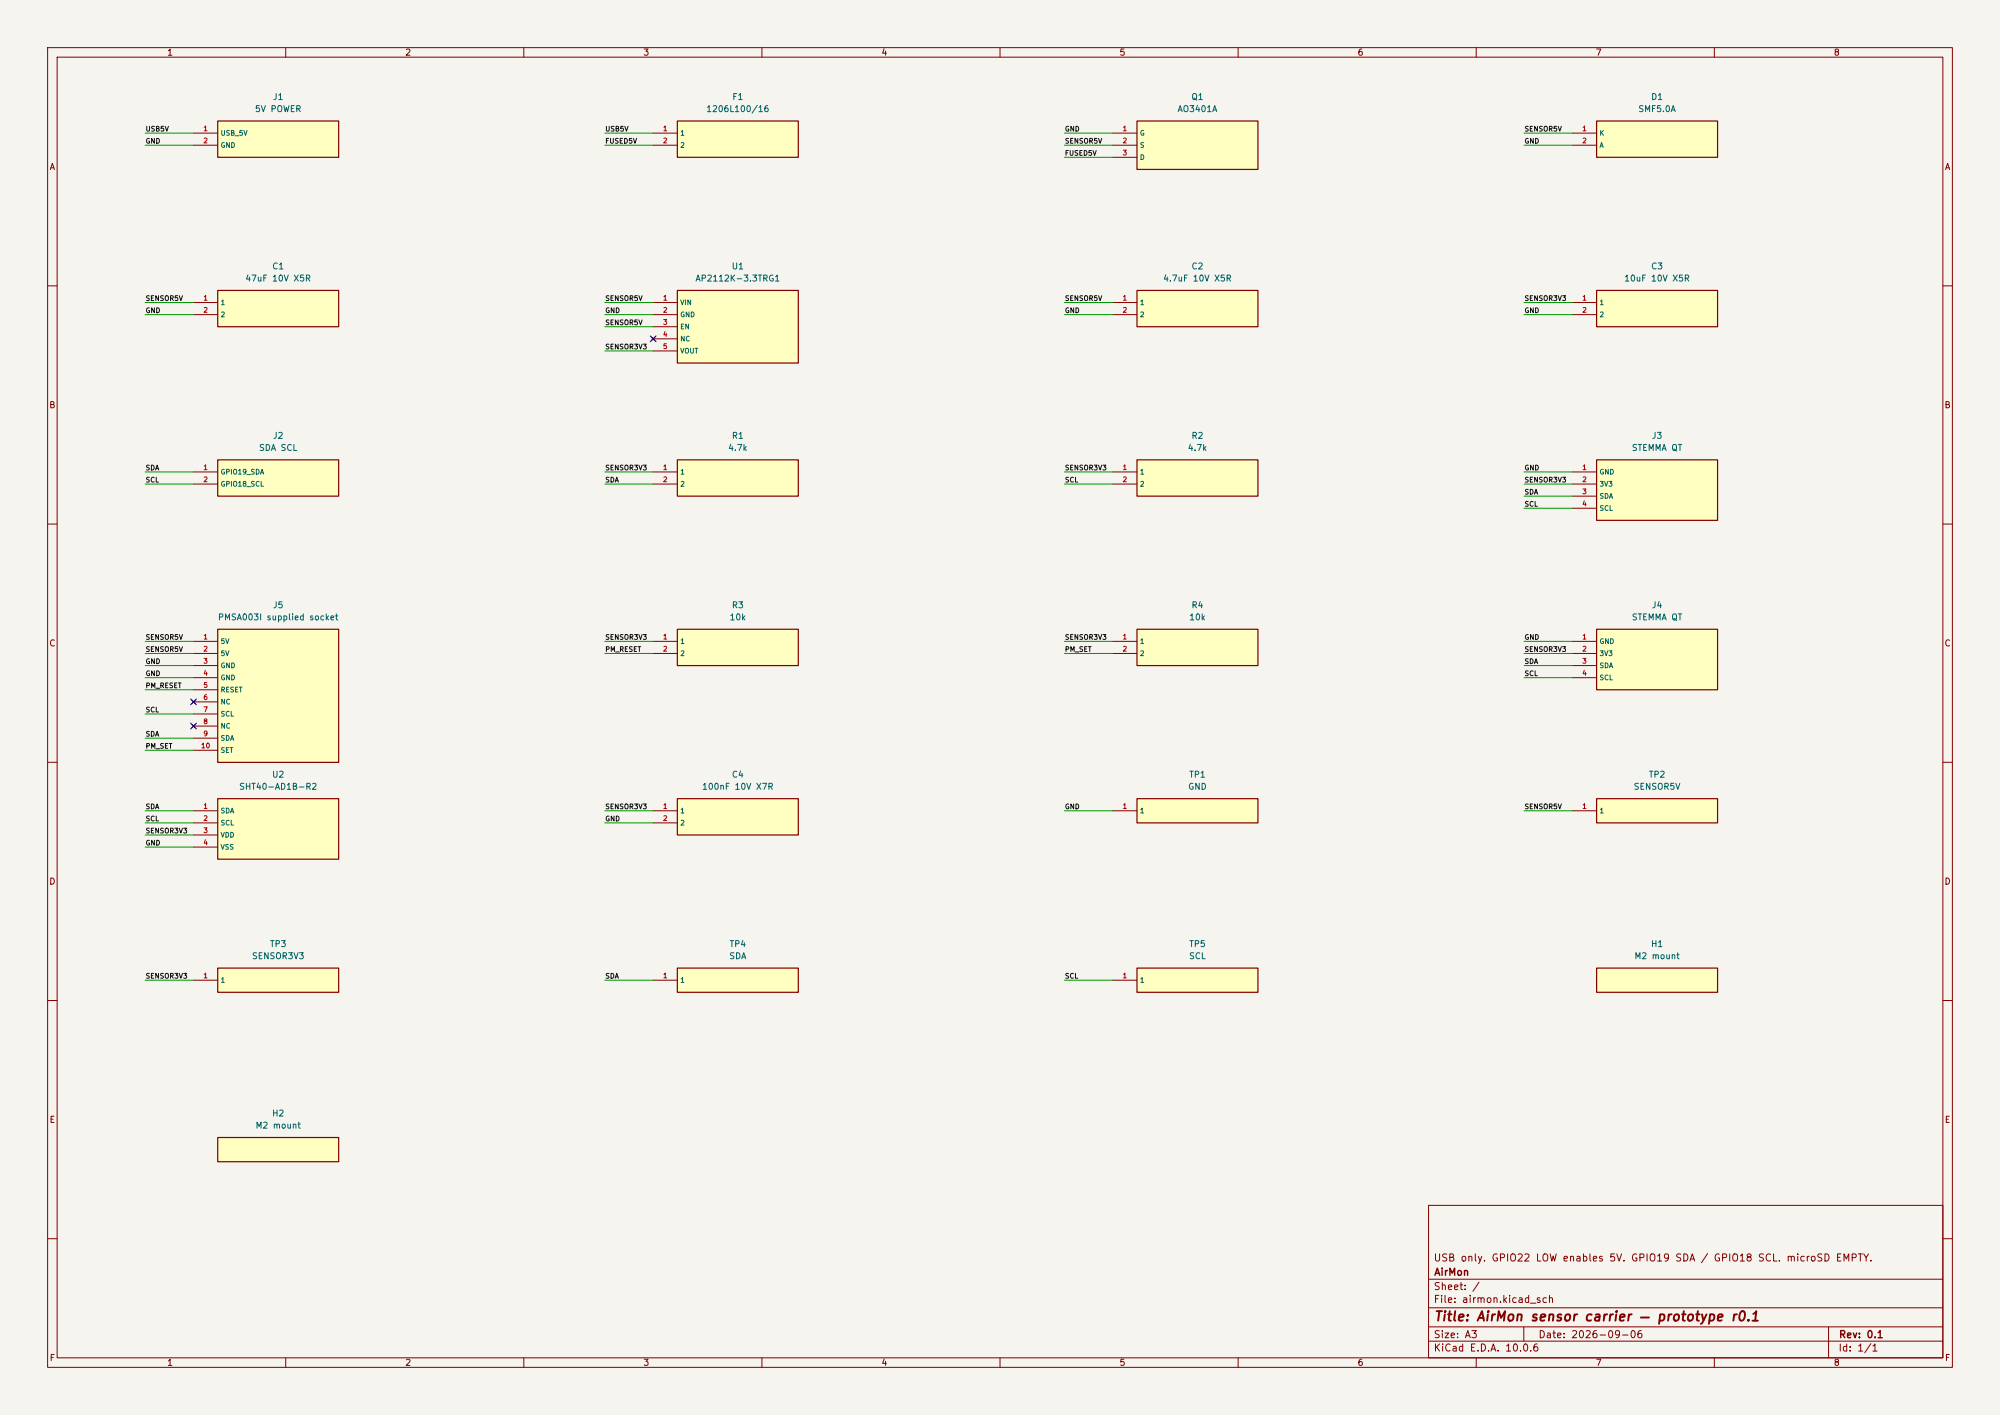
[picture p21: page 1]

USB only. GPIO22 LOW enables 5V. GPIO19 SDA / GPIO18 SCL. microSD EMPTY.
AirMon
Sheet: /
File: airmon.kicad_sch
Title: AirMon sensor carrier — prototype r0.1

Size: A3 | Rev: 0.1 | F Date: 2026-09-06
KiCad E.D.A. 10.0.6 | Id: 1/1

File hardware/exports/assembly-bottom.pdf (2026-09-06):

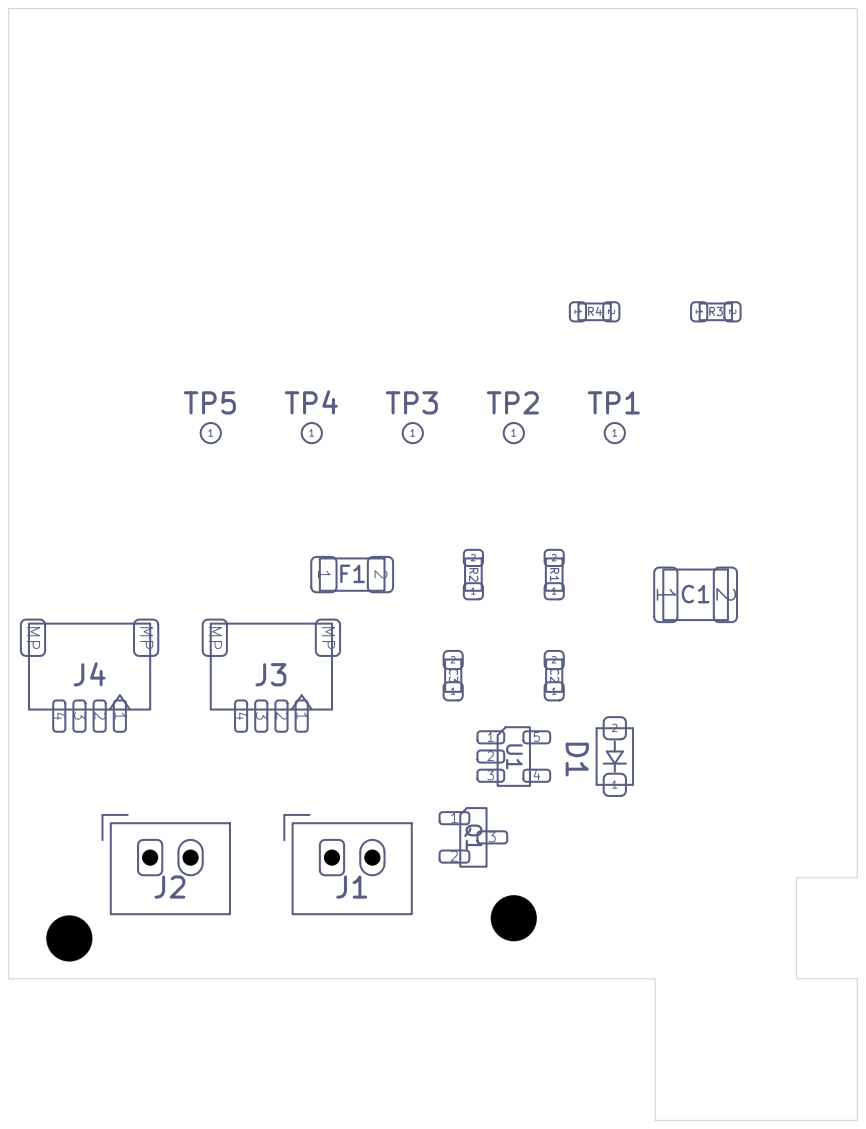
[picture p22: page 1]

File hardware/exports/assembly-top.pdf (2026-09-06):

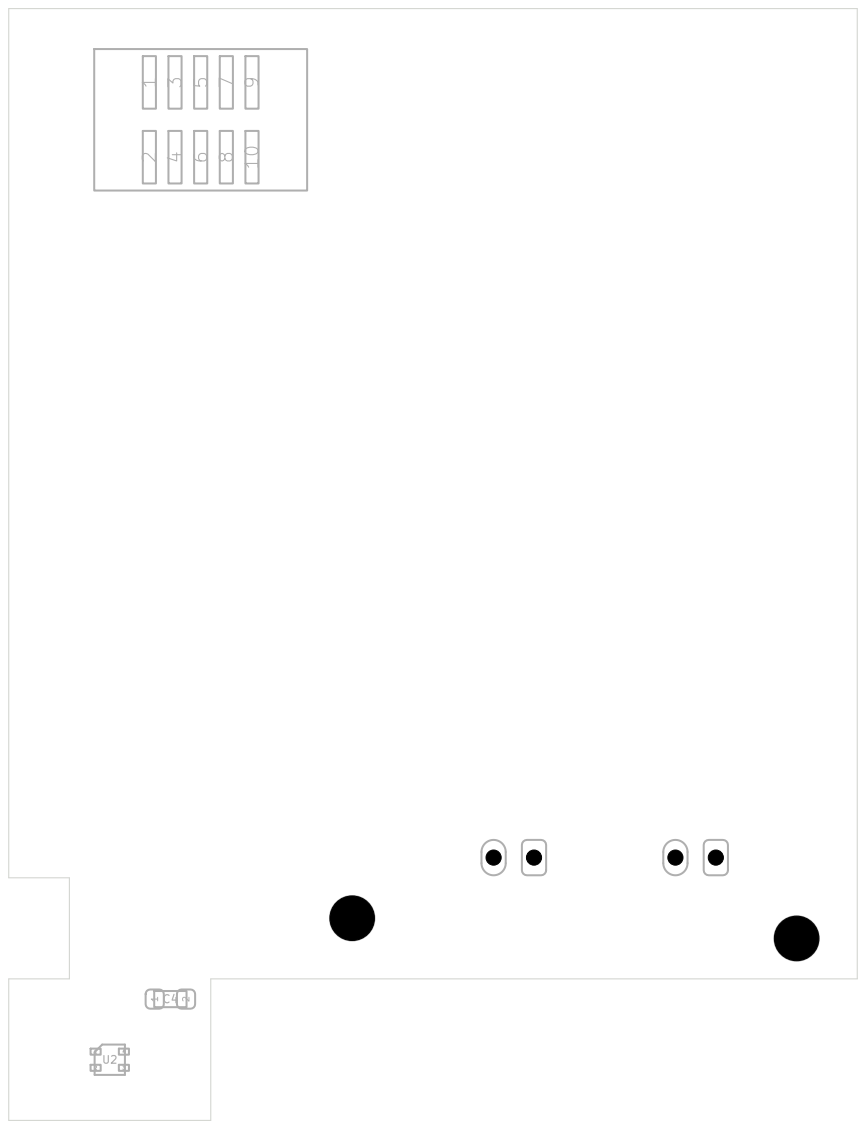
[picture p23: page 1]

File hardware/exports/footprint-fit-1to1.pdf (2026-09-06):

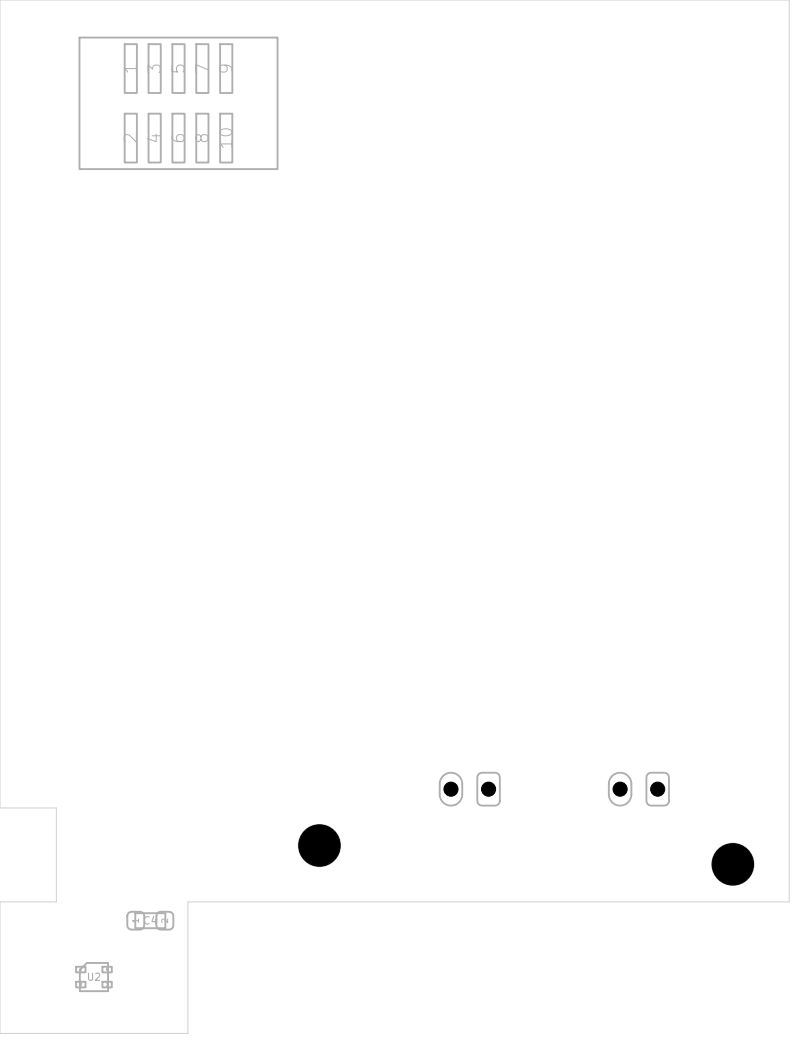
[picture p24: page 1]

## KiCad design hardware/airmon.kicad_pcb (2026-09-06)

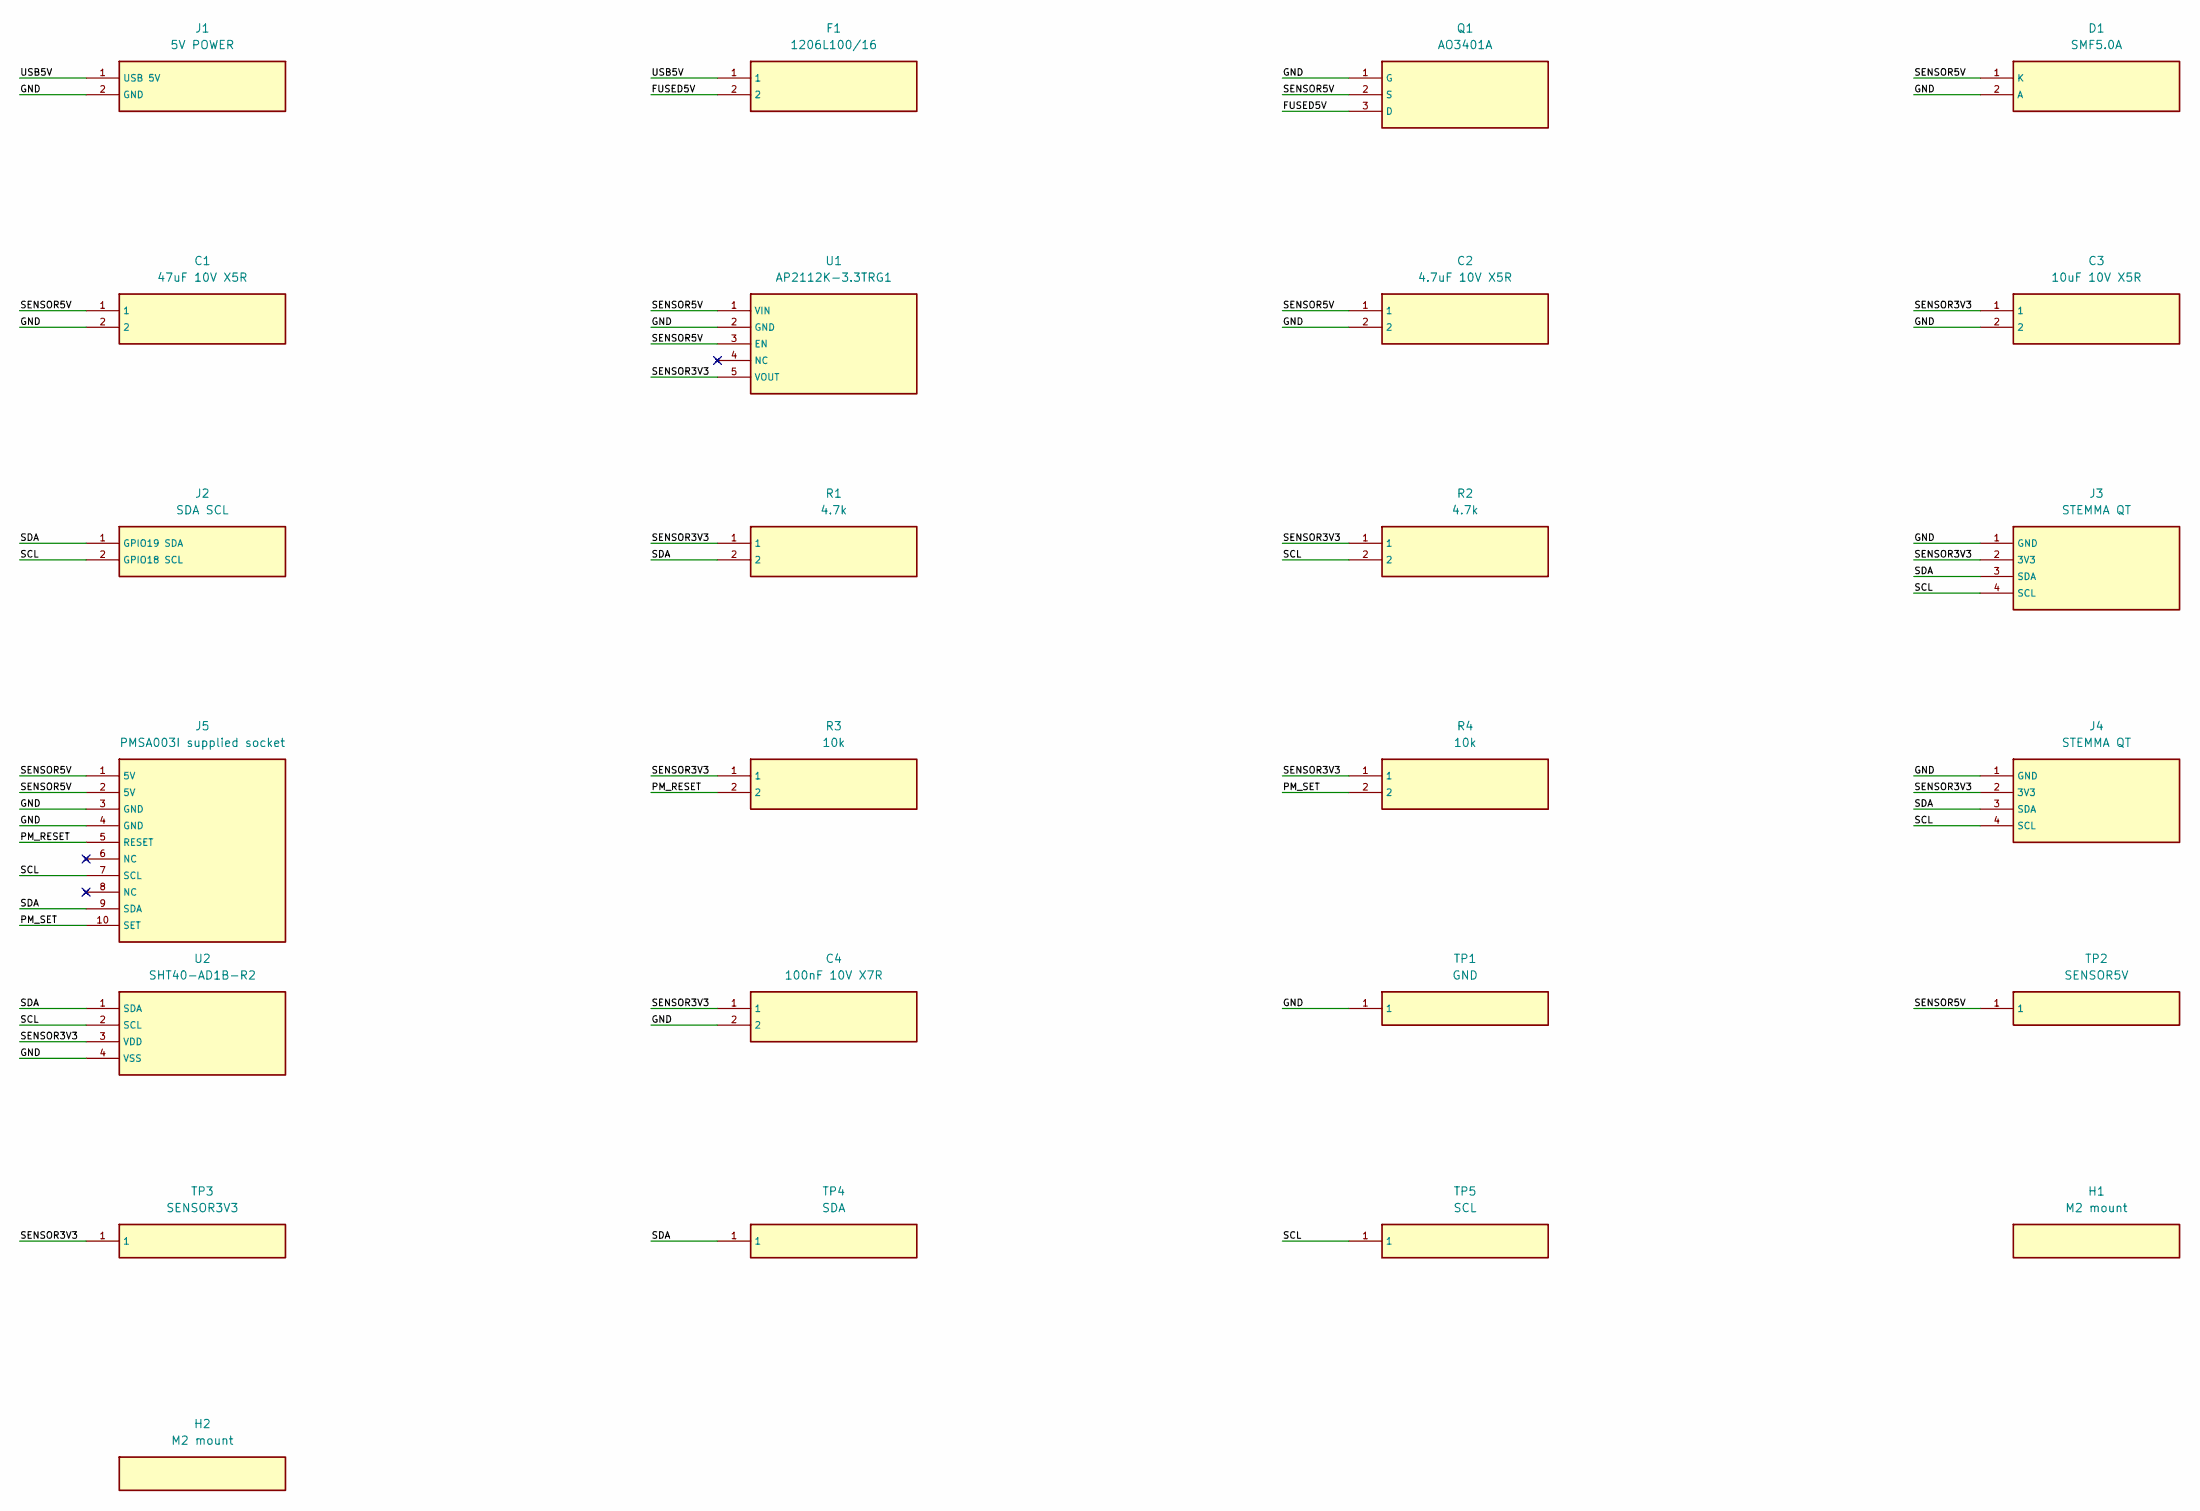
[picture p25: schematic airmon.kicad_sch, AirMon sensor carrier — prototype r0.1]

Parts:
C1: 47uF 10V X5R; C_1210_3225Metric
C2: 4.7uF 10V X5R; C_0603_1608Metric
C3: 10uF 10V X5R; C_0603_1608Metric
C4: 100nF 10V X7R; C_0603_1608Metric
D1: SMF5.0A; D_SOD-123F
F1: 1206L100/16; Fuse_1206_3216Metric
H1, H2: M2 mount; MountingHole_2.2mm_M2
J1: 5V POWER; JST_PH_B2B-PH-K_1x02_P2.00mm_Vertical
J2: SDA SCL; JST_PH_B2B-PH-K_1x02_P2.00mm_Vertical
J3, J4: STEMMA QT; JST_SH_SM04B-SRSS-TB_1x04-1MP_P1.00mm_Horizontal
J5: PMSA003I supplied socket; PMSA003I_SuppliedSocket
Q1: AO3401A; SOT-23
R1, R2: 4.7k; R_0603_1608Metric
R3, R4: 10k; R_0603_1608Metric
TP1: GND; TestPoint_Pad_D1.0mm
TP2: SENSOR5V; TestPoint_Pad_D1.0mm
TP3: SENSOR3V3; TestPoint_Pad_D1.0mm
TP4: SDA; TestPoint_Pad_D1.0mm
TP5: SCL; TestPoint_Pad_D1.0mm
U1: AP2112K-3.3TRG1; SOT-23-5
U2: SHT40-AD1B-R2; Sensirion_DFN-4_1.5x1.5mm_P0.8mm_SHT4x_NoCentralPad

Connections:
FUSED5V: F1.2, Q1.3 (D)
GND: C1.2, C2.2, C3.2, C4.2, D1.2 (A), J1.2 (GND), J3.1 (GND), J4.1 (GND), J5.3 (GND), J5.4 (GND), Q1.1 (G), TP1.1, U1.2 (GND), U2.4 (VSS)
PM_RESET: J5.5 (RESET), R3.2
PM_SET: J5.10 (SET), R4.2
SCL: J2.2 (GPIO18 SCL), J3.4 (SCL), J4.4 (SCL), J5.7 (SCL), R2.2, TP5.1, U2.2 (SCL)
SDA: J2.1 (GPIO19 SDA), J3.3 (SDA), J4.3 (SDA), J5.9 (SDA), R1.2, TP4.1, U2.1 (SDA)
SENSOR3V3: C3.1, C4.1, J3.2 (3V3), J4.2 (3V3), R1.1, R2.1, R3.1, R4.1, TP3.1, U1.5 (VOUT), U2.3 (VDD)
SENSOR5V: C1.1, C2.1, D1.1 (K), J5.1 (5V), J5.2 (5V), Q1.2 (S), TP2.1, U1.1 (VIN), U1.3 (EN)
USB5V: F1.1, J1.1 (USB 5V)

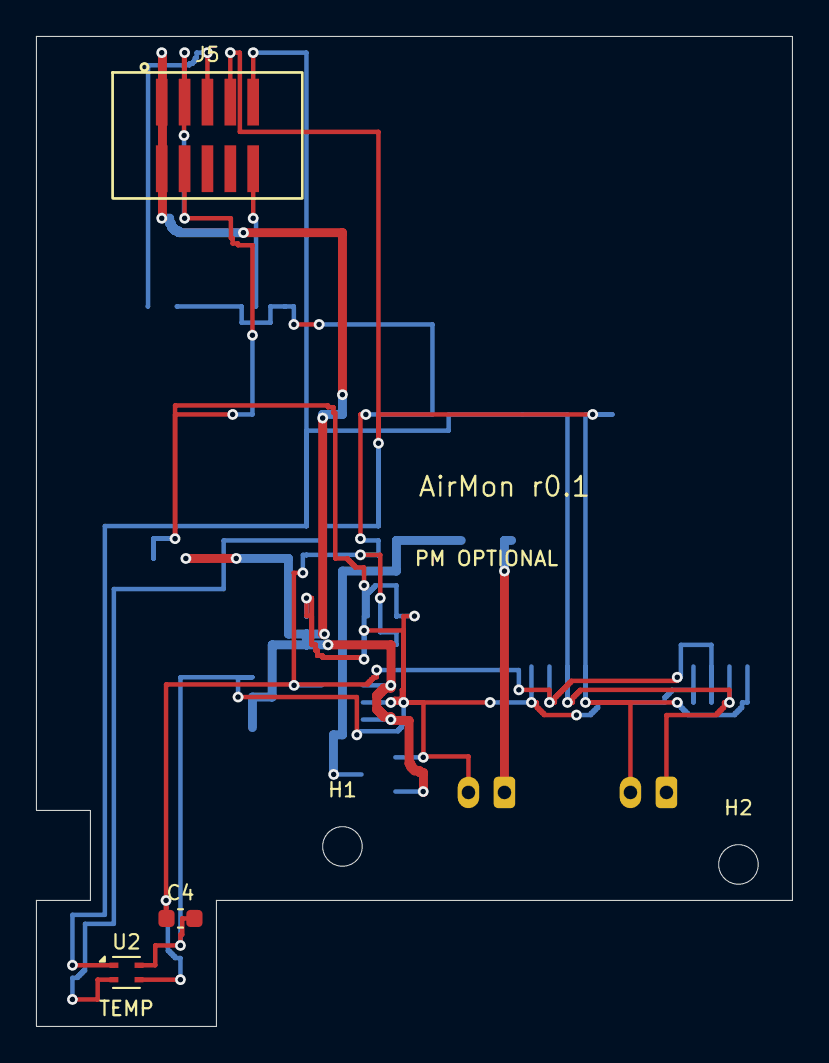
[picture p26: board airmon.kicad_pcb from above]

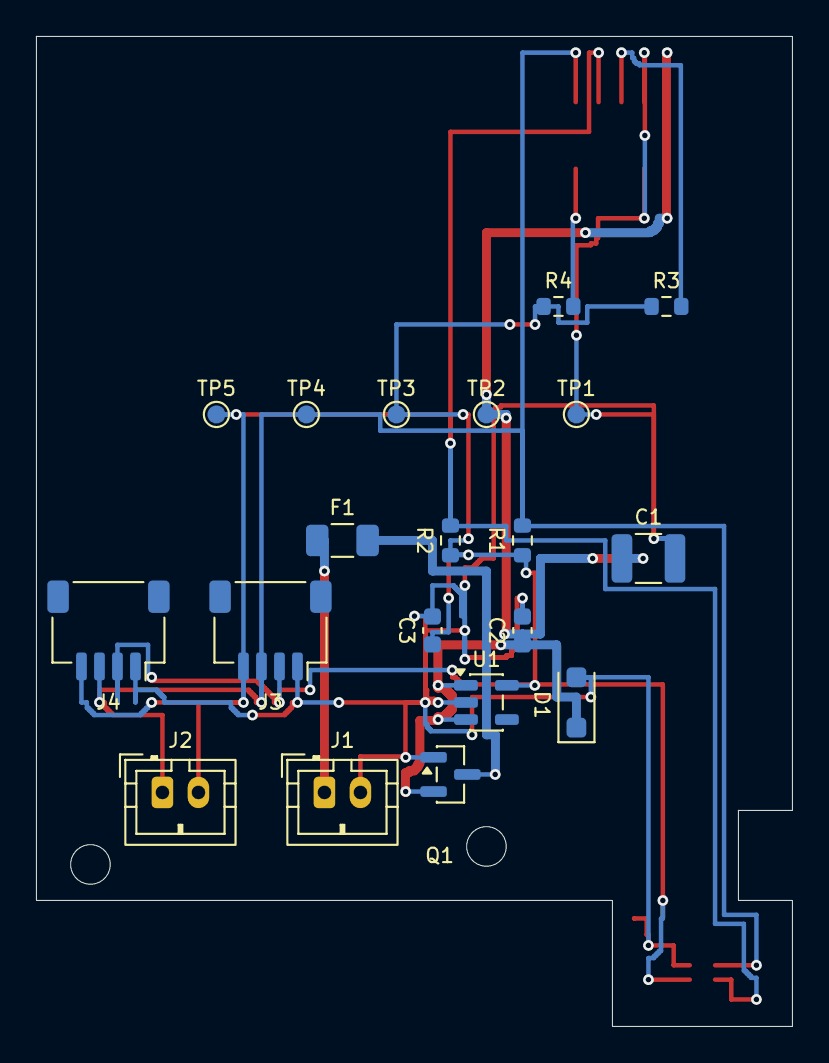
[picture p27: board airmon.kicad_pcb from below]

Board: 2 copper layers, 42.0 x 55.0 mm, 25 parts (20 on the bottom side), 9 nets.

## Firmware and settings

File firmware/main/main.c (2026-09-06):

#include "airmon.h"
#include <time.h>
#include "esp_timer.h"
#include "esp_ota_ops.h"
#include "esp_log.h"
#include "driver/gpio.h"
#include "nvs_flash.h"

am_app app;
uint64_t am_now(void) {return (uint64_t)esp_timer_get_time()/1000;}
uint32_t am_utc(void) {time_t t=time(NULL);return t>1700000000?(uint32_t)t:0;}
void app_main(void) {
    app.mutex=xSemaphoreCreateMutex();configASSERT(app.mutex);
    /* Board Q5 supplies UART pin 1. GPIO22 also lights the red LED. */
    gpio_set_level(GPIO_NUM_22,0);gpio_set_direction(GPIO_NUM_22,GPIO_MODE_OUTPUT);
    gpio_set_level(GPIO_NUM_4,1);gpio_set_direction(GPIO_NUM_4,GPIO_MODE_OUTPUT); /* audio off */
    gpio_set_level(GPIO_NUM_5,1);gpio_set_direction(GPIO_NUM_5,GPIO_MODE_OUTPUT); /* deselect SD */
    gpio_set_level(GPIO_NUM_16,1);gpio_set_direction(GPIO_NUM_16,GPIO_MODE_OUTPUT);
    gpio_set_level(GPIO_NUM_17,1);gpio_set_direction(GPIO_NUM_17,GPIO_MODE_OUTPUT);
    esp_err_t err=nvs_flash_init();
    /* Never erase credentials silently when storage cannot be opened. */
    ESP_ERROR_CHECK(err);
    am_config_init();
    am_network_start();
    am_sensors_start();
    am_web_start();
    am_display_start();
    vTaskDelay(pdMS_TO_TICKS(10000));
    /* Optional sensors and an unavailable router do not invalidate firmware. */
    esp_ota_img_states_t state;
    if(esp_ota_get_state_partition(esp_ota_get_running_partition(),&state)==ESP_OK && state==ESP_OTA_IMG_PENDING_VERIFY)
        ESP_ERROR_CHECK(esp_ota_mark_app_valid_cancel_rollback());
    ESP_LOGI("airmon","Startup complete; firmware %s",AM_VERSION);
}

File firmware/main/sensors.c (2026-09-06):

#include "airmon.h"
#include <math.h>
#include <string.h>
#include "driver/i2c_master.h"
#include "freertos/queue.h"
#include "sensirion_gas_index_algorithm.h"

typedef struct {uint8_t address; i2c_master_dev_handle_t dev;bool online,ever;unsigned failures;uint64_t since;} sensor;
static sensor devices[4]={{.address=0x44},{.address=0x12},{.address=0x62},{.address=0x59}};
static i2c_master_bus_handle_t bus;
static QueueHandle_t calibrations;
static GasIndexAlgorithmParams voc,nox;
static const unsigned first[4]={AM_TEMP,AM_PM1,AM_CO2,AM_VOC},last[4]={AM_RH,AM_PM10,AM_CO2,AM_NOX};
static uint64_t co2_started;

static bool command(sensor *s,uint16_t command,const uint16_t *args,size_t count,uint16_t *out,size_t words,unsigned wait) {
    uint8_t b[20]={(uint8_t)(command>>8),(uint8_t)command};
    for(size_t i=0;i<count;i++){b[2+i*3]=args[i]>>8;b[3+i*3]=args[i];b[4+i*3]=am_crc8(b+2+i*3,2);}
    if(i2c_master_transmit(s->dev,b,2+count*3,100)!=ESP_OK)return false;
    if(wait)vTaskDelay(pdMS_TO_TICKS(wait));
    if(!words)return true;
    return i2c_master_receive(s->dev,b,words*3,100)==ESP_OK && am_sensirion_words(b,words*3,out);
}
static void set_state(unsigned id,am_state state) {
    am_lock();for(unsigned m=first[id];m<=last[id];m++)app.readings[m].state=state;am_unlock();
}
static void publish(unsigned metric,float value,am_state state) {
    am_lock();app.readings[metric]=(am_reading){.value=value,.at_ms=am_now(),.state=state};am_unlock();
}
static bool start_co2(sensor *s,const am_config *c) {
    if(!command(s,0x3f86,NULL,0,NULL,0,500))return false;
    uint16_t asc=c->co2_asc,alt=c->altitude_m;
    if(!command(s,0x2416,&asc,1,NULL,0,2)||!command(s,0x2427,&alt,1,NULL,0,2)||!command(s,0x21b1,NULL,0,NULL,0,1))return false;
    am_lock();co2_started=am_now();am_unlock();return true;
}
static void discover(unsigned i,const am_config *c) {
    sensor *s=&devices[i];
    if(i2c_master_probe(bus,s->address,100)!=ESP_OK){set_state(i,s->ever?AM_FAILED:AM_ABSENT);return;}
    bool ok=true;
    if(i==2)ok=start_co2(s,c);
    if(i==3) {
        uint16_t result=0;ok=command(s,0x280e,NULL,0,&result,1,320)&&result==0xd400;
        GasIndexAlgorithm_init(&voc,GasIndexAlgorithm_ALGORITHM_TYPE_VOC);
        GasIndexAlgorithm_init(&nox,GasIndexAlgorithm_ALGORITHM_TYPE_NOX);
    }
    s->online=ok;s->ever=true;s->failures=0;s->since=am_now();set_state(i,ok?AM_WARMING:AM_FAILED);
}
static void failed(unsigned i) {
    sensor *s=&devices[i];s->failures++;
    am_lock();app.sensor_errors[i]++;am_unlock();
    if(s->failures>=3){s->online=false;set_state(i,AM_FAILED);}else set_state(i,AM_STALE);
}
bool am_sensors_calibrate(uint16_t ppm) {
    am_lock();bool valid=am_reading_current(&app.readings[AM_CO2],am_now(),15000) && am_now()-co2_started>=180000;am_unlock();
    return calibrations && ppm>=400 && ppm<=2000 && valid && xQueueSend(calibrations,&ppm,0)==pdTRUE;
}
static void task(void *unused) {
    (void)unused;
    am_config cfg,applied;am_config_get(&applied);
    vTaskDelay(pdMS_TO_TICKS(1000));
    for(unsigned i=0;i<4;i++)discover(i,&applied);
    TickType_t wake=xTaskGetTickCount();unsigned tick=0;
    for(;;) {
        am_config_get(&cfg);uint64_t now=am_now();
        if(devices[2].online && (cfg.co2_asc!=applied.co2_asc || cfg.altitude_m!=applied.altitude_m)) {
            if(!start_co2(&devices[2],&cfg))failed(2);else set_state(2,AM_WARMING);
        }
        applied=cfg;
        if(tick%30==0)for(unsigned i=0;i<4;i++)if(!devices[i].online)discover(i,&cfg);
        if(devices[0].online) {
            uint8_t cmd=0xfd,b[6];float t,rh;
            bool ok=i2c_master_transmit(devices[0].dev,&cmd,1,100)==ESP_OK;
            vTaskDelay(pdMS_TO_TICKS(10));
            ok=ok && i2c_master_receive(devices[0].dev,b,6,100)==ESP_OK && am_decode_sht4x(b,&t,&rh);
            if(ok){publish(AM_TEMP,t+cfg.temperature_offset,AM_VALID);publish(AM_RH,rh,AM_VALID);devices[0].failures=0;}else failed(0);
        }
        if(devices[1].online) {
            uint8_t b[32];uint16_t pm[3];
            if(i2c_master_receive(devices[1].dev,b,sizeof(b),100)==ESP_OK && am_decode_pmsa003i(b,sizeof(b),pm)) {
                am_state state=now-devices[1].since>=30000?AM_VALID:AM_WARMING;
                for(int i=0;i<3;i++)publish(AM_PM1+i,pm[i],state);
                devices[1].failures=0;
            }else failed(1);
        }
        if(devices[2].online && tick%5==0) {
            uint16_t ready=0,w[3];
            bool ok=command(&devices[2],0xe4b8,NULL,0,&ready,1,2);
            if(ok && (ready&0x7ff)) {
                ok=command(&devices[2],0xec05,NULL,0,w,3,2)&&w[0]>0;
                if(ok){publish(AM_CO2,w[0],AM_VALID);devices[2].failures=0;}
            }
            if(!ok)failed(2);
        }
        if(devices[3].online) {
            am_reading t,rh;am_lock();t=app.readings[AM_TEMP];rh=app.readings[AM_RH];am_unlock();
            bool compensation=am_reading_current(&t,am_now(),5000)&&am_reading_current(&rh,am_now(),5000);
            uint16_t args[2]={0x8000,0x6666},w[2];
            if(compensation){args[0]=(uint16_t)lroundf(fminf(100,fmaxf(0,rh.value))*65535/100);args[1]=(uint16_t)lroundf((fminf(130,fmaxf(-45,t.value))+45)*65535/175);}
            bool conditioning=am_now()-devices[3].since<10000;
            bool ok=command(&devices[3],conditioning?0x2612:0x2619,args,2,w,conditioning?1:2,50);
            if(ok) {
                devices[3].failures=0;
                if(conditioning){set_state(3,AM_WARMING);}
                else {
                    int32_t vi=0,ni=0;GasIndexAlgorithm_process(&voc,w[0],&vi);GasIndexAlgorithm_process(&nox,w[1],&ni);
                    /* Datasheet index settling: VOC 1.5 h, NOx 6 h. */
                    uint64_t elapsed=am_now()-devices[3].since;
                    publish(AM_VOC,vi,compensation?(elapsed>=5400000&&vi>0?AM_VALID:AM_WARMING):AM_STALE);
                    publish(AM_NOX,ni,compensation?(elapsed>=21600000&&ni>0?AM_VALID:AM_WARMING):AM_STALE);
                }
            }else failed(3);
        }
        uint16_t reference;
        if(xQueueReceive(calibrations,&reference,0)==pdTRUE) {
            set_state(2,AM_WARMING);uint16_t correction;
            bool ok=command(&devices[2],0x3f86,NULL,0,NULL,0,500) && command(&devices[2],0x362f,&reference,1,&correction,1,400) && correction!=0xffff;
            bool restart=start_co2(&devices[2],&cfg);
            am_lock();strlcpy(app.config_result,ok&&restart?"CO2 calibration complete":"CO2 calibration failed",sizeof(app.config_result));am_unlock();
            if(!restart)failed(2);
        }
        am_lock();
        for(int i=0;i<AM_METRICS;i++)if(app.readings[i].state==AM_VALID && !am_reading_current(&app.readings[i],am_now(),i==AM_CO2?15000:5000))app.readings[i].state=AM_STALE;
        am_history_sample(&app.history,am_now(),am_utc(),app.readings);
        am_unlock();tick++;vTaskDelayUntil(&wake,pdMS_TO_TICKS(1000));
    }
}
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

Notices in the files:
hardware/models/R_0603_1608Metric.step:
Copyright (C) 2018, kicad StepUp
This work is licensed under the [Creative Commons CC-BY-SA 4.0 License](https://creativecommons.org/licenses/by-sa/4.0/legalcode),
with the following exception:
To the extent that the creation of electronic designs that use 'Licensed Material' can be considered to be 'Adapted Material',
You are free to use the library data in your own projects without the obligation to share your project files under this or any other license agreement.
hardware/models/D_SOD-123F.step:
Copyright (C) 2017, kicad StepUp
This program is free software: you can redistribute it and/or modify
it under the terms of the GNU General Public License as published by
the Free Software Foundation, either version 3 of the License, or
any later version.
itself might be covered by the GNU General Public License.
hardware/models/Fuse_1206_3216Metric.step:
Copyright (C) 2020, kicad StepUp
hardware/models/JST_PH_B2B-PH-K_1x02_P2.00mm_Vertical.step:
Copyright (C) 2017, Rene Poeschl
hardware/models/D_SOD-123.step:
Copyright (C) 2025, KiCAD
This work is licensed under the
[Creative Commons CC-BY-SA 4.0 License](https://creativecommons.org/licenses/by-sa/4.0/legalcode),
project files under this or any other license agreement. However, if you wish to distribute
